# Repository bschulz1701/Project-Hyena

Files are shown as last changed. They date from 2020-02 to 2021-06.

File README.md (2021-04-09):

# Project-Hyena
Daughterboard for use with Feather form factor controller, designed to interface with multiple, flexible, low cost sensors at the core of a low cost meteorological sensing system. 

# Repo Outline
#### [Documents](Documents/) 

General document and image storage for repo and README

#### [Hardware](Hardware/)

Current board files (Eagle), Bill of Materials (BoM), and other design documents

#### [Production](Production/)

Contains the various Gerber and pick and place files required to have the Printed Circuit Boards (PCBs) manufactured or populated 

#### [Software](Software/)

The software associated with the piece of hardware, this is usually diagnostic software used for verifying or investigating the hardware

#### [Testing](Testing/)

Scripts and results from the testing process and development process. Contains more detailed information about documented issues among other testing. 

## Overview
* **Type:** Data Logger/Daughterboard 
* **Interfaces:** I<sup>2</sup>C, GPIO, Pulse
* **Release Version:** v0.2 - 2020/07/15

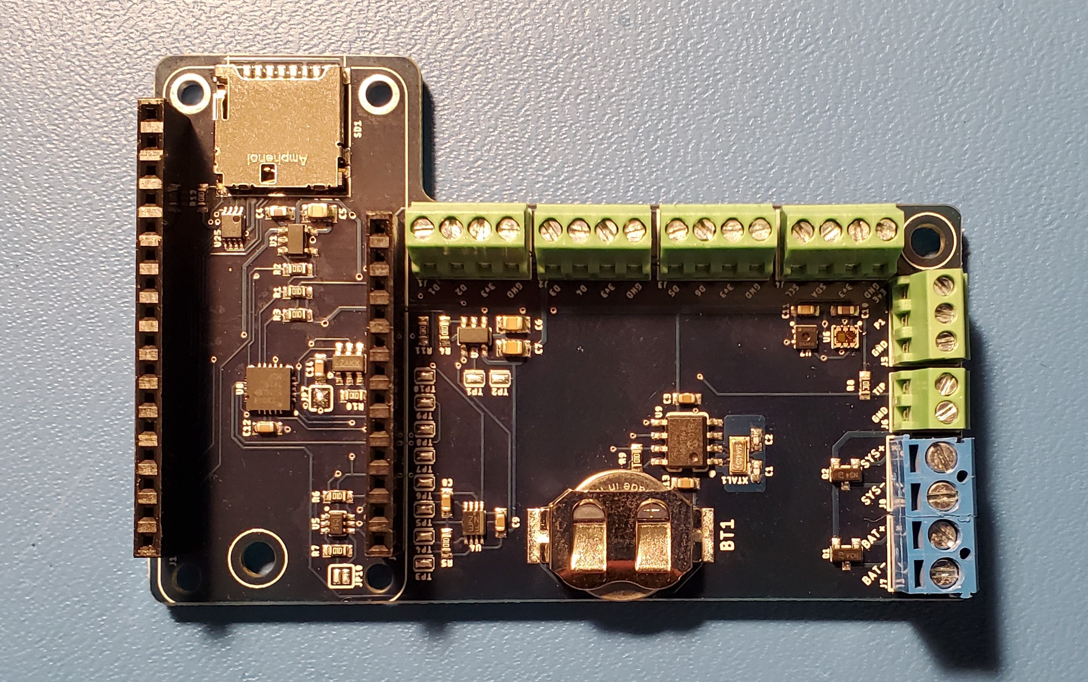
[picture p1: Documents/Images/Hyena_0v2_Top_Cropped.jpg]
Hyena v0.2 - Top


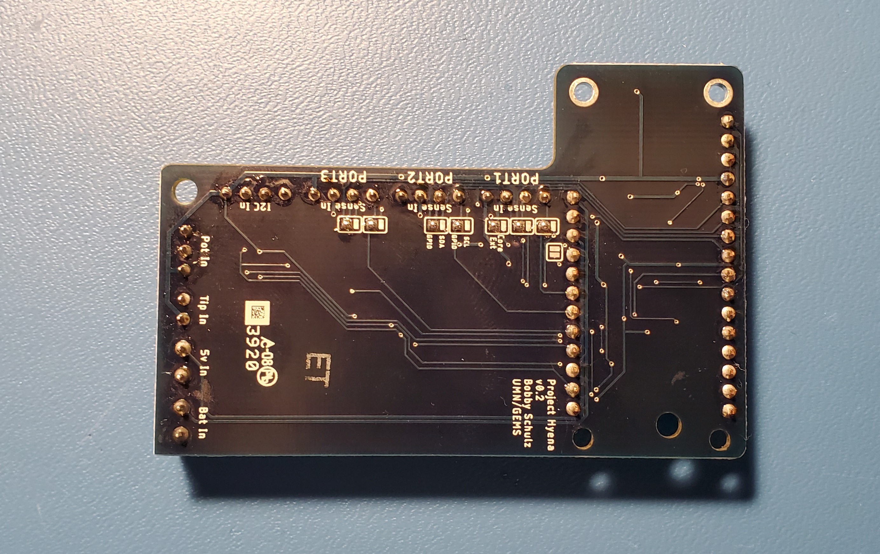
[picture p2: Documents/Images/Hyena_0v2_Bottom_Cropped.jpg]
Hyena v0.2 - Bottom


## Features
### On-Board
* Micro SD Card 
* RTC w/Battery Backup
* Temperature/Pressure/RH Sensor
* RGB Ambient Light Sensor
* Reverse Polarity Power Protected Inputs 

### Interface
* Tipping Bucket Input (SPST switch compatible)
* Dedicated Potentiometric Input (x1) 
* Flexible Sensor Inputs (x3)
* Dedicated I<sup>2</sup>C Input (x1) 
* Supports Particle and other Feather based controllers 

## Specifications
* **Sensor Voltage:** 3.3V
* **Sensor Current (Max):** 500mA (Combined)

## Jumper Settings 

**Port Select Jumpers**
| Jumper | Purpose | Position 1 | Position 2 | 
| --- | --- | --- | --- |
| `JP1`	| GPIO vs I<sup>2</sup>C - Port 1 Digital | Select I2C | Select GPIO | 
| `JP2` | GPIO vs I<sup>2</sup>C - Port 1 Analog | Select I2C | Select GPIO | 
| `JP3` | GPIO vs I<sup>2</sup>C - Port 2 Digital | Select I2C | Select GPIO | 
| `JP4` | GPIO vs I<sup>2</sup>C - Port 2 Analog | Select I2C | Select GPIO | 
| `JP5` | GPIO vs I<sup>2</sup>C - Port 3 Digital | Select I2C | Select GPIO | 
| `JP6` | GPIO vs I<sup>2</sup>C - Port 3 Analog | Select I2C | Select GPIO | 
| `JP8` | Power Select (Core vs Ext) - Port 1 | Core Power for Port 1 | External Switched Power for Port 1 |

**Configuration Jumpers**
| Jumper | Purpose | Open | Closed | Default | 
| --- | --- | --- | --- | ----- |
| `JP7` | Enable Hardware WDT | WDT Disabled | WDT Enabled | Closed |  
| `JP9` | Pullup for Port 1 Digital GPIO | Pullup Disabled | Pullup Enabled | Open |
| `JP10` | Gang On-Board and External I2C Buses | I2C Combined | I2C Isolated | Open | 

## Known Issues/Errata

#### WDT Disable

**Issue:** If using Particle Boron as controller and if you have the WDT disabled (leave `JP7` open), the system fails to run properly, or has sporadic resets. This is likely due to parasitic current on the reset line of the Boron.

**Workaround:** Make sure WDT is enabled by closing `JP7`

#### Solder Jumper Stencil

**Issue:** Depending on the thickness of the solder stencil used for populating the board, the solder jumpers may not bridge when desired. This is due to lack of stencil thickness specification and pad geometry.

**Workaround:** Make a note on the board assembly (if working with a board house) as to which jumpers should be connected (see jumper tables). Otherwise, if assembling manually, check the jumpers are connected, and bridge them using solder wire and a soldering iron if they have failed to jump where desired.

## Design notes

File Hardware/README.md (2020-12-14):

# Hardware Overview - Project Hyena

## Files

* [Legacy](Legacy/) - File storage for older hardware versions  
* PrimaryLogger.sch - Eagle Schematic
* PrimaryLogger.brd - Eagle Board File
* [PrimaryLogger_BoM.csv](PrimaryLogger_BoM.csv) - BoM (For reference only, see [Production](../Production) for production ready BoM)
* [PrimaryLogger.pdf](PrimaryLogger_0v2.pdf) - PDF of Schematic 

## I2C Addresses 

| Device | Address | 
| --- | --- |
| MCP23008 | 0x20 | 
| TCS3400 | 0x39 |
| MCP7940 | 0x6F |
| SHTC3 | 0x70 |

## Pinout

| Particle Pin | Hyena Pin Name | Control | Function | 
| --- | --- | --- | --- |
| 8 | `3V3_EXT_EN` | Output | Enables the external 3.3v rail (active high, nominally low) | 
| 7 | `WD_HOLD` | Output | Controls the hardware watchdog timer, pulse high to "feed" timer |
| 6 | `GPIO1D` | IO | General digital IO pin for external sensors (J1 Connector) | 
| 5 | `GPIO2D` | IO | General digital IO pin for external sensors (J2 Connector) | 
| 4 | `GPIO3D` | IO | General digital IO pin for external sensors (J3 Connector) | 
| 3 | `RTC_INT` | Input | Interrupt line from RTC, natively high active low (open drain), triggers on falling edge |
| 2 | `SDA_CTRL` | Output | Used to turn internal I2C on or off (active high, I2C_OB on, natively low) |
| 1 | `SCL` | Output | I2C clock line |
| 0 | `SDA` | IO | I2C Data line |
| 9 | `3V3_SD_EN` | Output | Enable line for SD card 3.3v supply (active high, natively low) |
| 10 | `IO_EXP_INT` | Input | Global interrupt from the IO expander (functionality configurable via software) |
| 11 | `MISO` | Input | MasterInSlaveOut, part of SPI bus |
| 12 | `MOSI` | Output | MasterOutSlaveIn, part of SPI bus | 
| 13 | `SCK` | Output | SerialClocK, part of SPI bus | 
| 14 | `SD_CS` | Output | SD chip select line, active low |
| 15/ADC4 | `TIP` | IO | Designed as tipping bucket rain gauge input, connected to J6, pulled high by default |
| 16/ADC3 | `GPIOXA` | IO | Intended as analog input for potentiometric input (J5) |
| 17/ADC2 | `GPIO1A` | IO | General digital/analog IO pin for external sensors (J1 Connector) |
| 18/ADC1 | `GPIO2A` | IO | General digital/analog IO pin for external sensors (J2 Connector) |
| 19/ADC0 | `GPIO3A` | IO | General digital/analog IO pin for external sensors (J3 Connector) |

| IO Expander Pin | Hyena Pin Name | Control | Function |
| --- | --- | --- | --- |
| 0 | `3V3_EXT_FAULT` | Input | Monitor pin for external 3v3 rail, if over current trip, pin is pulled low, natively high |
| 1 | `3V3_SD_FAULT` | Input | Monitor pin for SD card 3v3 rail, if over current trip, pin is pulled low, natively high |
| 2 | `SD_CD` | Input | Card detect pin for SD card, natively high, pulled low to indicate physical presence of SD card | 
| 3 | `I2C_EXT_EN` | Output | Control line for external I2C buffer, natively high (on), can be pulled low to turn off the external I2C bus | 
| 4 | `PAR_INT` | Input | Event interrupt line from TCS3400 light sensor (used for PAR measurement), active low interrupt |

## Hardware Testing:
See Testing sub folder

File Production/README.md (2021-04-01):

# Production
This folder contains files used to have the hardware manufactured 

## Files

#### Version v0.2 - Release Version

* [Geber](0v2_Release/PrimaryLogger_2020-09-17_x274.zip)
* [Top Mount](0v2_Release/PrimaryLogger_v2.mnt)
* [BoM](0v2_Release/PrimaryLogger_v2_BoM.csv)

### File Conventions 
* `HardwareName.mnb` - These are mount files (pick and place) for the bottom of the board
* `HardwareName.mnt` - These are mount files (pick and place) for the top of the board
* `HardwareName_YYYY-MM-DD_x274.zip` - These are Gerber (PCB) files from a given date in x274 format, which is accepted by most board houses   

#### Notes:

* Take note of Solder Jumper Stencil issue under Errata 
* A [CR1220](https://www.digikey.com/en/products/detail/panasonic-bsg/CR1220/269740) coin cell battery is required

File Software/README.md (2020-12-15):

# Software
Used for testing or as an accompaniment to hardware devices 

## Files
### Dev

* [`ExternalResetTest.ino`](ExternalResetTest/ExternalResetTest.ino)
	* Development program used to measure timing/functionality of hardware WDT

### Diagnostics 

*  [`HardwareTest.ino`](HardwareTest/HardwareTest.ino)
	* A test designed to be run on a feather board installed in the logger to test the functionality of the system, used to verify the daughterboard hardware

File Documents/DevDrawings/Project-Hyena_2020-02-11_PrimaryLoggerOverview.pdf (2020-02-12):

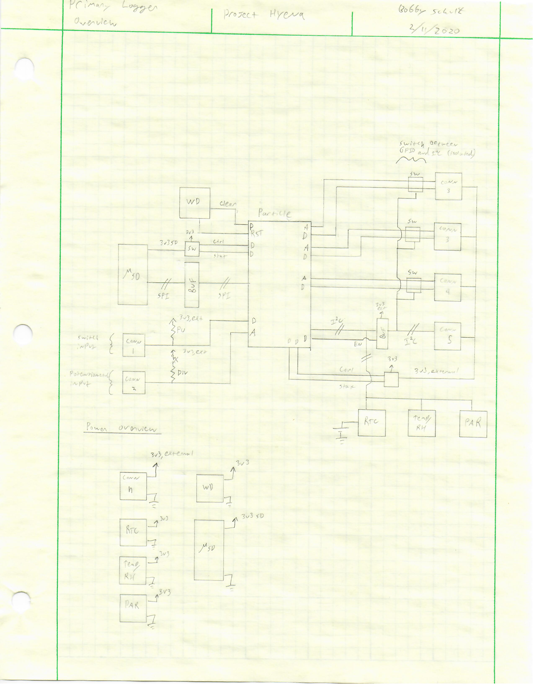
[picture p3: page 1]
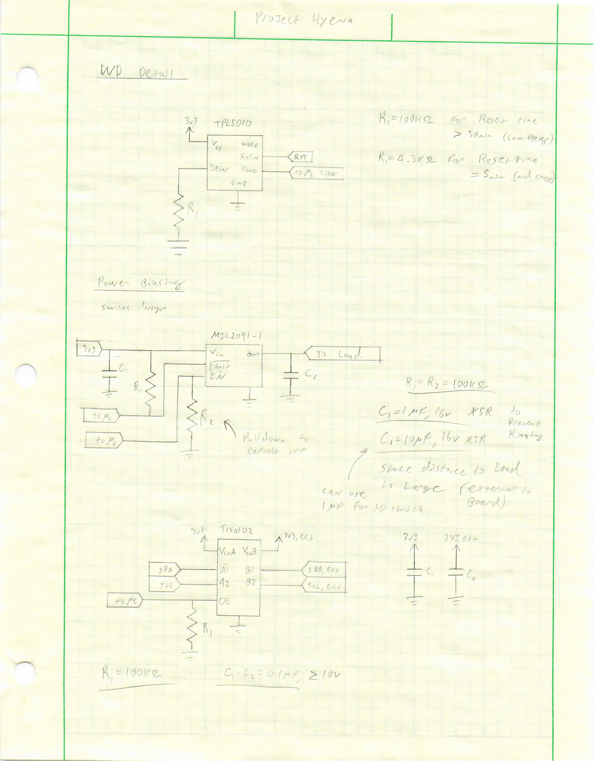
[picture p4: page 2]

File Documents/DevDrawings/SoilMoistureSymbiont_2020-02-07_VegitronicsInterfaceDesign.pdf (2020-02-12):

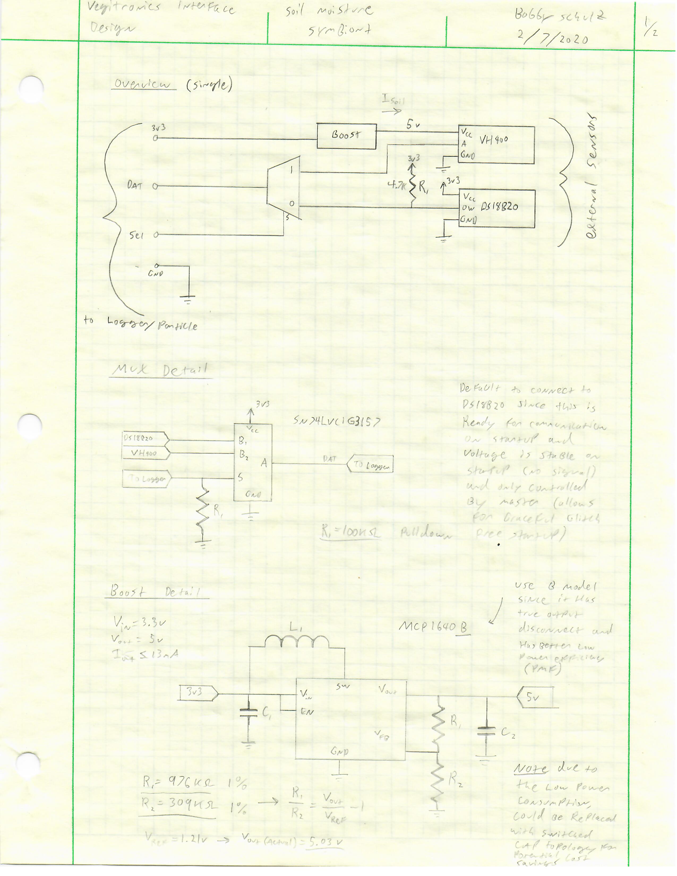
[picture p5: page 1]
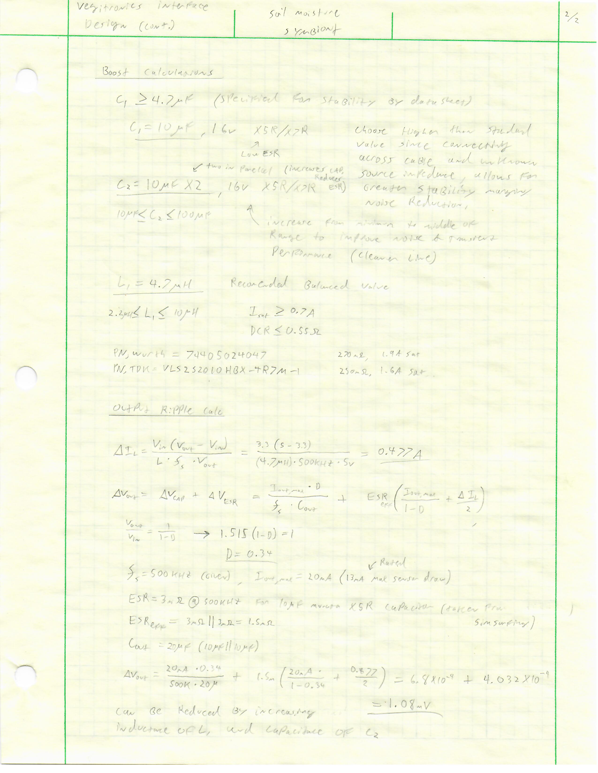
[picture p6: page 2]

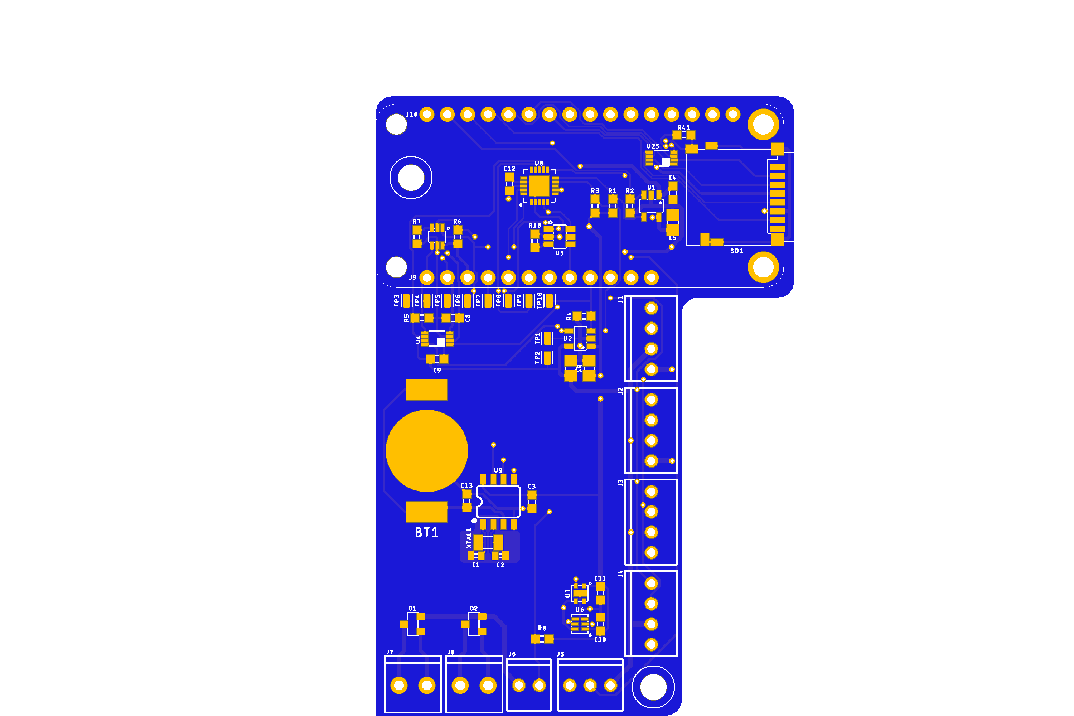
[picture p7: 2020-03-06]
Hardware/PrimaryLogger_0v0_Render.png

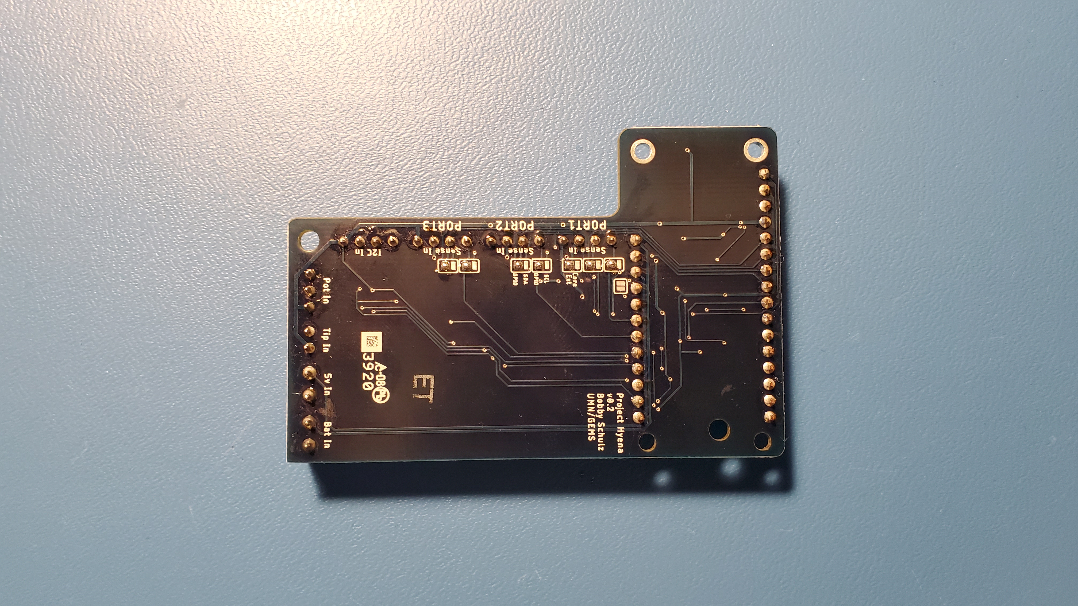
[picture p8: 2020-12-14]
Documents/Images/Hyena_0v2_Bottom.jpg

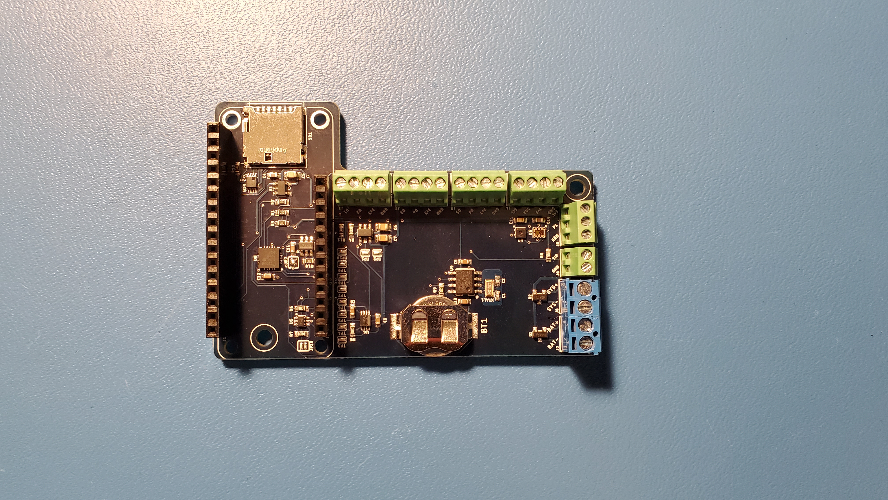
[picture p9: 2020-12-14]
Documents/Images/Hyena_0v2_Top.jpg

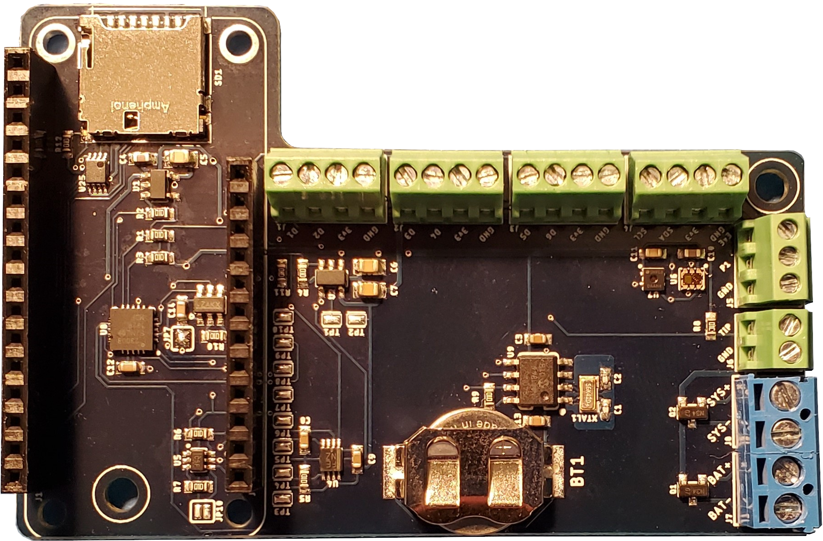
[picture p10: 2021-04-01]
Documents/Images/Hyena_0v2_Top_Cropped.png

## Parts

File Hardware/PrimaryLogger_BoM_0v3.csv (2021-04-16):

Qty | Value | Device | Package | Parts | Description | DIGIKEY | DISP | MF | MPN | VALUE | VALUE_PART
1 |  | CONN_022.54_SCREW_ROUND | 1X02_2.54_SCREWTERM_ROUND | J8 | Genaric 2 terminal header | ED10561-ND |  | OnShore | OSTVN02A150
2 |  | CONN_023.5MM_ROUND | SCREWTERMINAL-3.5MM-2_ROUND | J6, J7 | Genaric 2 terminal header | ED2635-ND |  | OnShore | OSTTE020161
2 |  | MOUNTING_HOLE2_NP | 2_56 | H1, H2 | Genaric Mechanical Mounting Hole | DNP |  | N/A | DNP
9 | 0.1uF | C-EU0.1UFC0603 | C0603 | C1, C2, C3, C7, C8, C9, C10, C16, C17 | CAPACITOR, European symbol | 490-6051-1-ND |  | Murata | GCM188R71E104KA57D
2 | 0R | R-EU_0.0R0603 | R0603 | R2, R16 | RESISTOR, European symbol | 311-0.0LECT-ND |  | Yageo | AC0603JR-070RL |  | 0
11 | 100k | R-EU_100KR0603 | R0603 | R1, R3, R4, R5, R7, R8, R13, R15, R18, R21, R22 | RESISTOR, European symbol | 311-100KHRCT-ND |  | Yageo | RC0603FR-07100KL |  | 100k
4 | 10k | R-EU_10KR0603 | R0603 | R6, R9, R10, R14 | RESISTOR, European symbol | 311-10.0KHRCT-ND |  | Yageo | RC0603FR-0710KL |  | 10k
4 | 10uF | C-EU10UFC0805 | C0805 | C11, C13, C14, C15 | CAPACITOR, European symbol | 490-6473-6-ND |  | Murata | GRM21BR61C106KE15K
1 | 1k | R-EU_1KR0603 | R0603 | R17 | RESISTOR, European symbol | 311-1KLDCT-ND |  | Yageo | AC0603FR-071KL |  | 1k
2 | 1uF | C-EU1UFC0603 | C0603 | C4, C12 | CAPACITOR, European symbol | 587-1251-1-ND |  | Yaiyo Yuden | EMK107BJ105KA-T
6 | 4.7k | R-EU_4.7KR0603 | R0603 | R11, R12, R19, R20, R23, R24 | RESISTOR, European symbol | 311-4.70KHRCT-ND |  | Yageo | RC0603FR-074K7L |  | 4.7k
2 | 6pF | C-EU6PFC0402 | C0402 | C5, C6 | CAPACITOR, European symbol | 490-3104-1-ND |  | Murata | GJM1555C1H6R0CB01D
1 | BATTERY_COIN12MM | BATTERY_COIN12MM | LINX_BAT-HLD-012-SMT | BT1 | Coin Cell Battery Holder | BAT-HLD-012-SMT-ND |  | Linx | BAT-HLD-012-SMT
1 | CONN_32.54_SCREW | CONN_32.54_SCREW | 1X03_SCREW | J5 | Genaric 3 terminal header | ED10562-ND |  | On Shore | OSTVN03A150
4 | CONN_42.54_SCREW | CONN_42.54_SCREW | 1X04_SCREW | J1, J2, J3, J4 | Genaric 4 terminal header | ED10563-ND |  | On Shore | OSTVN04A150
1 | CRYSTAL3.2X1.5 | CRYSTAL3.2X1.5 | CRYSTAL_3.2X1.5_2-SMD | XTAL1 | Crystal Oscilator | 535-11937-1-ND |  | ABS07-120-32.768KHZ-T | Abracon
2 | DMG3404 | MOSFET-NCH-DMG3404L | SOT23-3 | Q1, Q2 | N-channel MOSFETs | DMG3404L-7DICT-ND |  | Diodes Incorporated | DMG3404L-7 | DMG3404
1 | FEATHERWING_NODIM | FEATHERWING_NODIM | FEATHERWING_DIM | MS1
1 | GEMS_POWER_PLUGINPUT | GEMS_POWER_PLUGINPUT | 2X3_MICROFIT_RT | J9 | Power Plug For GEMS Based SystemsBoth Input and Output versions | WM1815-ND | Input | Molex | 0430450600
1 | JUMPER-SMT_2_NC_PASTE_SILK | JUMPER-SMT_2_NC_PASTE_SILK | SMT-JUMPER_2_NC_PASTE_SILK | JP8 | Normally closed solder jumper | DNP |  | N/A | N/A
7 | JUMPER-SMT_3_1-NC_PASTE_SILK | JUMPER-SMT_3_1-NC_PASTE_SILK | SMT-JUMPER_3_1-NC_PASTE_SILK | JP1, JP2, JP3, JP4, JP5, JP6, JP7 | Normally closed solder jumper (1 of 2 connections) | DNP |  | N/A | N/A
1 | LEDGREEN0603 | LEDGREEN0603 | LED_0603 | D2 | Genaric LED | 732-4971-1-ND |  | Wurth | 150060GS75000
2 | LEDRED0603 | LEDRED0603 | LED_0603 | D1, D3 | Genaric LED | 732-4978-1-ND |  | Wurth | 150060RS75000
1 | MCP23008SSOP | MCP23008SSOP | SSOP20 | U3 | MCP23008 - I2C I/O Expander, 8 bit wtih interrupt and reset | MCP23008T-E/SSCT-ND |  | Microchip | MCP23008T-E/SS
1 | MCP79412SOIC | MCP79412SOIC | SO08 | U1 | MCP794xx - Battery Backed I2C Real Time Clock (RTC) with SRAM (EEPROM*) and Protected EERPOM | MCP79412-I/SN-ND | MCP79412 | Microchip | MCP79412-I/SN
2 | MIC2005 | MIC2005 | SOT23-5 | U7, U8 | MIC2005 - Hight Side Load Switch, with Fixed Current Limit | 576-3462-1-ND | MIC2005 | Microchip | MIC2005A-1YM5-TR
1 | MIC842L | MIC842L | DCK_R-PDSO-G5 | U9 | Comparator with internal voltage referance (1.24V), 5V and 3.3V compatable, 20mA output current | 576-2927-1-ND |  | Microchip | MIC842LYC5-TR
1 | MICRO_SD | MICRO_SD | CUSTOM-PARTS_SD_MICRO | SD1 | Micro SD Card - Card Detect, Exposed leads for non-reflow soldering | 114-00841-68-1-ND |  | Amphenol | 114-00841-68
1 | PCA9617TSSOP8 | PCA9617TSSOP8 | TTSOP_8 | U10 | PCA9617A - Level translating I2C Bus Repeater | 568-10211-2-ND |  | NXP | PCA9617ADPJ
1 | SHTC3DFN | SHTC3DFN | DFN_4_2X2 | U4 | SHTCx - Digital Humidity and Temperature Sensor | 1649-1100-1-ND | SHTC3 | Sensirion | SHTC3
1 | SN74AUP3G34DCU | SN74AUP3G34DCU | DCU_(R-PDSO-G8) | U11 | SN74AUP3G34 - Logic Buffer | 296-25595-1-ND |  | TI | SN74AUP3G34DCUR
1 | SN74LVC1G3157SC70 | SN74LVC1G3157SC70 | DCK_R-PDSO-G6 | U12 | SN74LVC1G3157 - SPDT Analog Switch | 296-14909-1-ND | SN74LVC1G3157 | TI | SN74LVC1G3157DCKR
1 | TCS3400 | TCS3400 | TCS3400 | U5 | TCS3400 - Ambient Multi-Band Light Sensor with I2C Interface | TCS34003FNMCT-ND |  | AMS | TCS34003FNM
10 | TESTPOINTRCU | TESTPOINTRCU | TESTPOINT_0603 | TP1, TP2, TP3, TP4, TP5, TP6, TP7, TP8, TP9, TP10 |  | A106145CT-ND |  | TE Connectivity | RCU-0C
2 | TPL5010DDC | TPL5010DDC | DDC_R-PDSO-G6 | U2, U6 | TPL5010 - Nano-Power System Timer with Watchdog Functionality | 296-38829-1-ND |  | TI | TPL5010DDCT

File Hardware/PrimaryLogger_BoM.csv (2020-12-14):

Qty | Value | Device | Package | Parts | Description | DIGIKEY | DISP | MF | MPN | VALUE | VALUE_PART
1 |  | CONN_022.54_SCREW_ROUND | 1X02_2.54_SCREWTERM_ROUND | J6 | Genaric 2 terminal header | ED10561-ND |  | OnShore | OSTVN02A150
2 |  | CONN_023.5MM_ROUND | SCREWTERMINAL-3.5MM-2_ROUND | J7, J8 | Genaric 2 terminal header | ED2635-ND |  | OnShore | OSTTE020161
2 |  | MOUNTING_HOLE4_NP | 4_40 | H1, H2 | Genaric Mechanical Mounting Hole | DNP |  | N/A | DNP
7 | 0.1uF | C-EU0.1UFC0603 | C0603 | C3, C8, C9, C11, C12, C13, C14 | CAPACITOR, European symbol | 490-6051-1-ND |  | Murata | GCM188R71E104KA57D
11 | 100k | R-EU_100KR0603 | R0603 | R1, R2, R3, R4, R5, R6, R7, R9, R10, R11, R12 | RESISTOR, European symbol | 311-100KHRCT-ND |  | Yageo | RC0603FR-07100KL |  | 100k
1 | 100k | R-EU_10KR0603 | R0603 | R8 | RESISTOR, European symbol | 311-10.0KHRCT-ND |  | Yageo | RC0603FR-0710KL |  | 10k
3 | 10uF | C-EU10UFC0805 | C0805 | C5, C6, C7 | CAPACITOR, European symbol | 490-6473-6-ND |  | Murata | GRM21BR61C106KE15K
2 | 1uF | C-EU1UFC0603 | C0603 | C4, C10 | CAPACITOR, European symbol | 587-1251-1-ND |  | Yaiyo Yuden | EMK107BJ105KA-T
2 | 6pF | C-EU6PFC0402 | C0402 | C1, C2 | CAPACITOR, European symbol | 490-3104-1-ND |  | Murata | GJM1555C1H6R0CB01D
1 | BATTERY_COIN12MM | BATTERY_COIN12MM | LINX_BAT-HLD-012-SMT | BT1 | Coin Cell Battery Holder | BAT-HLD-012-SMT-ND |  | Linx | BAT-HLD-012-SMT
1 | CONN_32.54_SCREW | CONN_32.54_SCREW | 1X03_SCREW | J5 | Genaric 3 terminal header | ED10562-ND |  | On Shore | OSTVN03A150
4 | CONN_42.54_SCREW | CONN_42.54_SCREW | 1X04_SCREW | J1, J2, J3, J4 | Genaric 4 terminal header | ED10563-ND |  | On Shore | OSTVN04A150
1 | CRYSTAL3.2X1.5 | CRYSTAL3.2X1.5 | CRYSTAL_3.2X1.5_2-SMD | XTAL1 | Crystal Oscilator | 535-11937-1-ND |  | ABS07-120-32.768KHZ-T | Abracon
2 | DMG3404 | MOSFET-NCH-DMG3404L | SOT23-3 | Q1, Q2 | N-channel MOSFETs | DMG3404L-7DICT-ND |  | Diodes Incorporated | DMG3404L-7 | DMG3404
1 | FEATHERWING_NODIM | FEATHERWING_NODIM | FEATHERWING_DIM | MS1
2 | JUMPER-SMT_2_NC_PASTE_SILK | JUMPER-SMT_2_NC_PASTE_SILK | SMT-JUMPER_2_NC_PASTE_SILK | JP7, JP9 | Normally closed solder jumper | DNP |  | N/A | N/A
1 | JUMPER-SMT_2_NO_SILK | JUMPER-SMT_2_NO_SILK | SMT-JUMPER_2_NO_SILK | JP10 | Normally open jumper | DNP |  | N/A | N/A
7 | JUMPER-SMT_3_1-NC_PASTE_SILK | JUMPER-SMT_3_1-NC_PASTE_SILK | SMT-JUMPER_3_1-NC_PASTE_SILK | JP1, JP2, JP3, JP4, JP5, JP6, JP8 | Normally closed solder jumper (1 of 2 connections) | DNP |  | N/A | N/A
1 | MCP23008QFN | MCP23008QFN | QFN20 | U8 | MCP23008 - I2C I/O Expander, 8 bit wtih interrupt and reset | MCP23008T-E/MLCT-ND |  | Microchip | MCP23008T-E/ML
1 | MCP7940SOIC | MCP7940SOIC | SO08 | U9 | MCP7940 - RTC | MCP7940N-I/SN-ND |  | Microchip | MCP7940N-I/SN
2 | MIC2005 | MIC2005 | SOT23-5 | U1, U2 | MIC2005 - Hight Side Load Switch, with Fixed Current Limit | 576-3462-1-ND | MIC2005 | Microchip | MIC2005A-1YM5-TR
1 | MICRO_SD | MICRO_SD | CUSTOM-PARTS_SD_MICRO | SD1 | Micro SD Card - Card Detect, Exposed leads for non-reflow soldering | 114-00841-68-1-ND |  | Amphenol | 114-00841-68
1 | SHTC3DFN | SHTC3DFN | DFN_4_2X2 | U7 | SHTCx - Digital Humidity and Temperature Sensor | 1649-1100-1-ND | SHTC3 | Sensirion | SHTC3
1 | SN74AUP3G34DCU | SN74AUP3G34DCU | DCU_(R-PDSO-G8) | U25 | SN74AUP3G34 - Logic Buffer | 296-25595-1-ND |  | TI | SN74AUP3G34DCUR
1 | SN74LVC1G3157SC70 | SN74LVC1G3157SC70 | DCK_R-PDSO-G6 | U5 | SN74LVC1G3157 - SPDT Analog Switch | 296-14909-1-ND | SN74LVC1G3157 | TI | SN74LVC1G3157DCKR
1 | TCS3400 | TCS3400 | TCS3400 | U6 | TCS3400 - Ambient Multi-Band Light Sensor with I2C Interface | TCS34003FNMCT-ND |  | AMS | TCS34003FNM
10 | TESTPOINTRCU | TESTPOINTRCU | TESTPOINT_0603 | TP1, TP2, TP3, TP4, TP5, TP6, TP7, TP8, TP9, TP10 |  | A106145CT-ND |  | TE Connectivity | RCU-0C
1 | TPL5010DDC | TPL5010DDC | DDC_R-PDSO-G6 | U3 | TPL5010 - Nano-Power System Timer with Watchdog Functionality | 296-38829-1-ND |  | TI | TPL5010DDCT
1 | TXS0102DCU | TXS0102DCU | DCU_(R-PDSO-G8) | U4 | TXS0102 - 2 Channel Bidirectional Voltage Level Translator | 296-21931-1-ND |  | TI | TXS0102DCUR

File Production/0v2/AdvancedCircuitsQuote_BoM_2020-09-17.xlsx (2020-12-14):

Description | Qty | Ref Des | Mfg P/N | Manufacturer | Distributor P/N
Genaric 2 terminal header | 1 | J6 | OSTVN02A150 | OSTVN02A150 | ED10561-ND
Genaric 2 terminal header | 2 | J7, J8 | OSTTE020161 | OSTTE020161 | ED2635-ND
Genaric Mechanical Mounting Hole | 2 | H1, H2 | DNP | DNP | DNP
CAPACITOR, European symbol | 7 | C3, C8, C9, C11, C12, C13, C14 | GCM188R71E104KA57D | GCM188R71E104KA57D | 490-6051-1-ND
RESISTOR, European symbol | 11 | R1, R2, R3, R4, R5, R6, R7, R9, R10, R11, R12 | RC0603FR-07100KL | RC0603FR-07100KL | 311-100KHRCT-ND
RESISTOR, European symbol | 1 | R8 | RC0603FR-0710KL | RC0603FR-0710KL | 311-10.0KHRCT-ND
CAPACITOR, European symbol | 3 | C5, C6, C7 | GRM21BR61C106KE15K | GRM21BR61C106KE15K | 490-6473-6-ND
CAPACITOR, European symbol | 2 | C4, C10 | EMK107BJ105KA-T | EMK107BJ105KA-T | 587-1251-1-ND
CAPACITOR, European symbol | 2 | C1, C2 | GJM1555C1H6R0CB01D | GJM1555C1H6R0CB01D | 490-3104-1-ND
Coin Cell Battery Holder | 1 | BT1 | BAT-HLD-012-SMT | BAT-HLD-012-SMT | BAT-HLD-012-SMT-ND
Genaric 3 terminal header | 1 | J5 | OSTVN03A150 | OSTVN03A150 | ED10562-ND
Genaric 4 terminal header | 4 | J1, J2, J3, J4 | OSTVN04A150 | OSTVN04A150 | ED10563-ND
Crystal Oscilator | 1 | XTAL1 | Abracon | Abracon | 535-11937-1-ND
N-channel MOSFETs | 2 | Q1, Q2 | DMG3404L-7 | DMG3404L-7 | DMG3404L-7DICT-ND
Normally closed solder jumper | 2 | JP7, JP9 | N/A | N/A | DNP
Normally open jumper | 1 | JP10 | N/A | N/A | DNP
Normally closed solder jumper (1 of 2 connections) | 7 | JP1, JP2, JP3, JP4, JP5, JP6, JP8 | N/A | N/A | DNP
MCP23008 - I2C I/O Expander, 8 bit wtih interrupt and reset | 1 | U8 | MCP23008T-E/ML | MCP23008T-E/ML | MCP23008T-E/MLCT-ND
MCP7940 - RTC | 1 | U9 | MCP7940N-I/SN | MCP7940N-I/SN | MCP7940N-I/SN-ND
MIC2005 - Hight Side Load Switch, with Fixed Current Limit | 2 | U1, U2 | MIC2005A-1YM5-TR | MIC2005A-1YM5-TR | 576-3462-1-ND
Micro SD Card - Card Detect, Exposed leads for non-reflow soldering | 1 | SD1 | 114-00841-68 | 114-00841-68 | 114-00841-68-1-ND
SHTCx - Digital Humidity and Temperature Sensor | 1 | U7 | SHTC3 | SHTC3 | 1649-1100-1-ND
SN74AUP3G34 - Logic Buffer | 1 | U25 | SN74AUP3G34DCUR | SN74AUP3G34DCUR | 296-25595-1-ND
SN74LVC1G3157 - SPDT Analog Switch | 1 | U5 | SN74LVC1G3157DCKR | SN74LVC1G3157DCKR | 296-14909-1-ND
TCS3400 - Ambient Multi-Band Light Sensor with I2C Interface | 1 | U6 | TCS34003FNM | TCS34003FNM | TCS34003FNMCT-ND
Generic Test Points | 10 | TP1, TP2, TP3, TP4, TP5, TP6, TP7, TP8, TP9, TP10 | N/A | N/A | DNP
TPL5010 - Nano-Power System Timer with Watchdog Functionality | 1 | U3 | TPL5010DDCT | TPL5010DDCT | 296-38829-1-ND
TXS0102 - 2 Channel Bidirectional Voltage Level Translator | 1 | U4 | TXS0102DCUR | TXS0102DCUR | 296-21931-1-ND
Generic 16 terminal header | 1 | J10 | PPPC161LFBN-RC | Sullins | S7049-ND
Generic 12 terminal header | 1 | J9 | PPPC121LFBN-RC | Sullins | S7045-ND

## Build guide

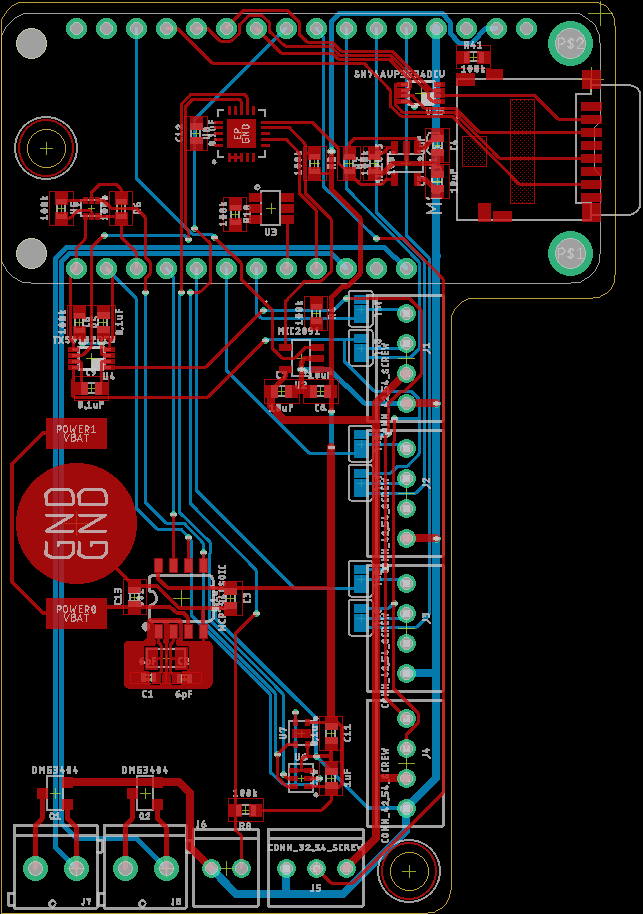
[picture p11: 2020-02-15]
Hardware/BoardPrint_ALPHA.png

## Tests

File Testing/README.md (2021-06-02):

# Testing:
## v0.0
### Hardware Watchdog:
Test functionality of watchdog (TPL5010) timer and confirm function with Particle Boron. 

Tested with Particle Boron connected to Feather socket, board powered via BatIn connection (3.7V power supply). Arduino was connected externally (common ground) and used to measure tripping on reset pin and timing of these pulses. The testing program was [ExternalResetTest](Software/ExternalResetTest/ExternalResetTest.ino). For the first test, the Boron was simply left in an idle state to ensure the watchdog would properly trigger at intervals. For the second test, the watchdog was reset by the Boron (via a high pulse 1ms in durration) every 5 minutes, which should prevent the watchdog from ever triggering. For all tests, a 100k&Omega; set resistor was used for the watchdog timer. 

Calculated period = 2159.65368 s (35.994 min)

T = [(((R<sub>Set</sub> x 2 x A)/100 + B )<sup>2</sup> - B<sup>2</sup>)/(4 x A) + C] / 100

for T > 1000s, A = 0.3177, B = -135.2571, C = 34522.4680 (See [Datasheet](http://www.ti.com/lit/ds/symlink/tpl5010.pdf) for more values/details)

<b>Test 1:</b>

<b>Test 2:</b>

## Alternative Parts:
Alternative clock, v0.4A board

| Previous Manufacturer Part Number | Previous Manufacturer | Alt Manufacturer Part Number | Alt Manufacturer | 
| --- | --- | ---- | ---- |
| ABS07-120-32.768KHZ-T | Abracon | ECS-.327-6-34QN-TR | ECS | 

Alternative crystal oscilation compaired with previous part on the v0.4A board, with MCP79412 RTC

**Standard Part**

Crystal Part Test

Yellow trace is connected to `X1` pin on RTC, blue trace is connected to `X2` pin on RTC, math output is CH1 - CH2

**Alt Part**

Crystal Alternative Part Test

Yellow trace is connected to `X1` pin on RTC, blue trace is connected to `X2` pin on RTC, math output is CH1 - CH2

## Issues:
### <b>Inrush current from Soil Moisture Symbiont (v0.0) trips external power switch</b>
<b>Cause:</b>
When the external switch is triggered with the Soil Moisture Symbiont connected, the inrush current on the soil moisture symbiont exceeds the current limit (100mA) on the load switch (MIC2091) for a long enough time to cause the fault detection to trip and disconnect the output. This results in a locked up state, since on each re-try the same overload occurs. 

Here we see the scope capture of the power on of the soil moisture symbiont when powered by a bench supply (current limit > max draw of soil moisture symbiont)
Power Supply Test

Yellow -> V<sub>Supply</sub>

Blue -> I<sub>Supply</sub> (10V/A)

<b>Potential Solutions:</b>

- Change boost converter on Soil Moisture Symbiont to a synchronous converter to prevent this inrush current. Fixes current problem, but not global potential issue. 
- Change load switch to one with a higher current limit, this would allow the current inrush current spike to be present without tripping the device into a locked out state.

<b>Testing:</b>

Switched the load switch to the MIC2005A load switch (identical pinout), which has a 500mA current limit, but otherwise the same functionality as the previous switch. The test of the system with this switch are seen below

MIC2005A Test

Yellow -> V<sub>Supply</sub>

Blue -> I<sub>Supply</sub> (10V/A)

As you can see, we get the same high value spike, but the switch does not trigger an overload and instead properly switches the output on.

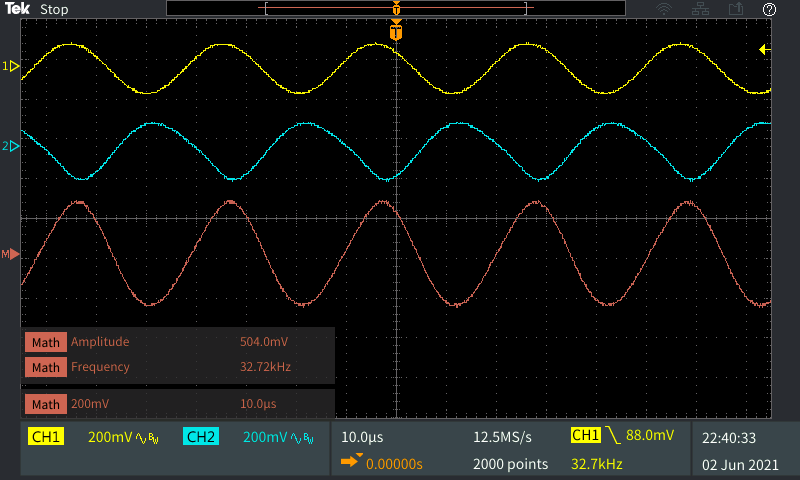
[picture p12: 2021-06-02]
Testing/TestingCaptures/CrystalTest_AltPart.PNG

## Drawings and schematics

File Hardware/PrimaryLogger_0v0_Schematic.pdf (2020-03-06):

A

A

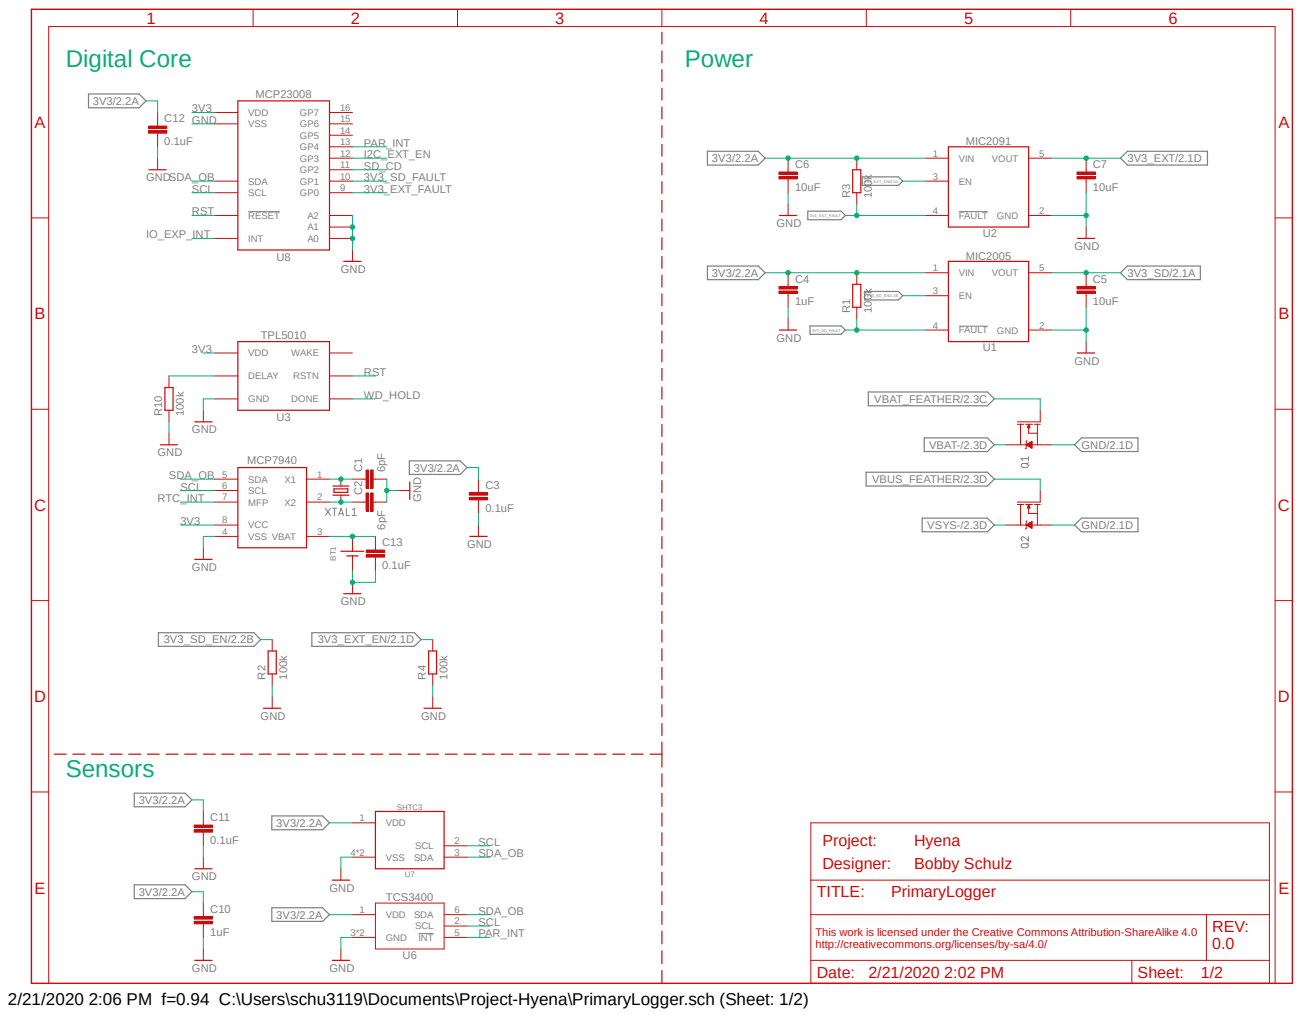
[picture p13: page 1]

This work is licensed under the Creative Commons Attribution-ShareAlike 4.0
http://creativecommons.org/licenses/by-sa/4.0/

TP2 TP1 TP4 TP5 TP6 TP3 TP10 TP7 TP9 TP8 CARD_DETECT CD¹ CARD_DETECT1 CD² | DATA_OUT
1Y | 7 GND 4 | VCC | 8 SN74AUP3G34 U25 A1 5 | A2 4 | VA 3 | VB | 7 EN | 6 B1 | 8 B2 | 1 TXS0102 GND 2 | U4 C8 | C9

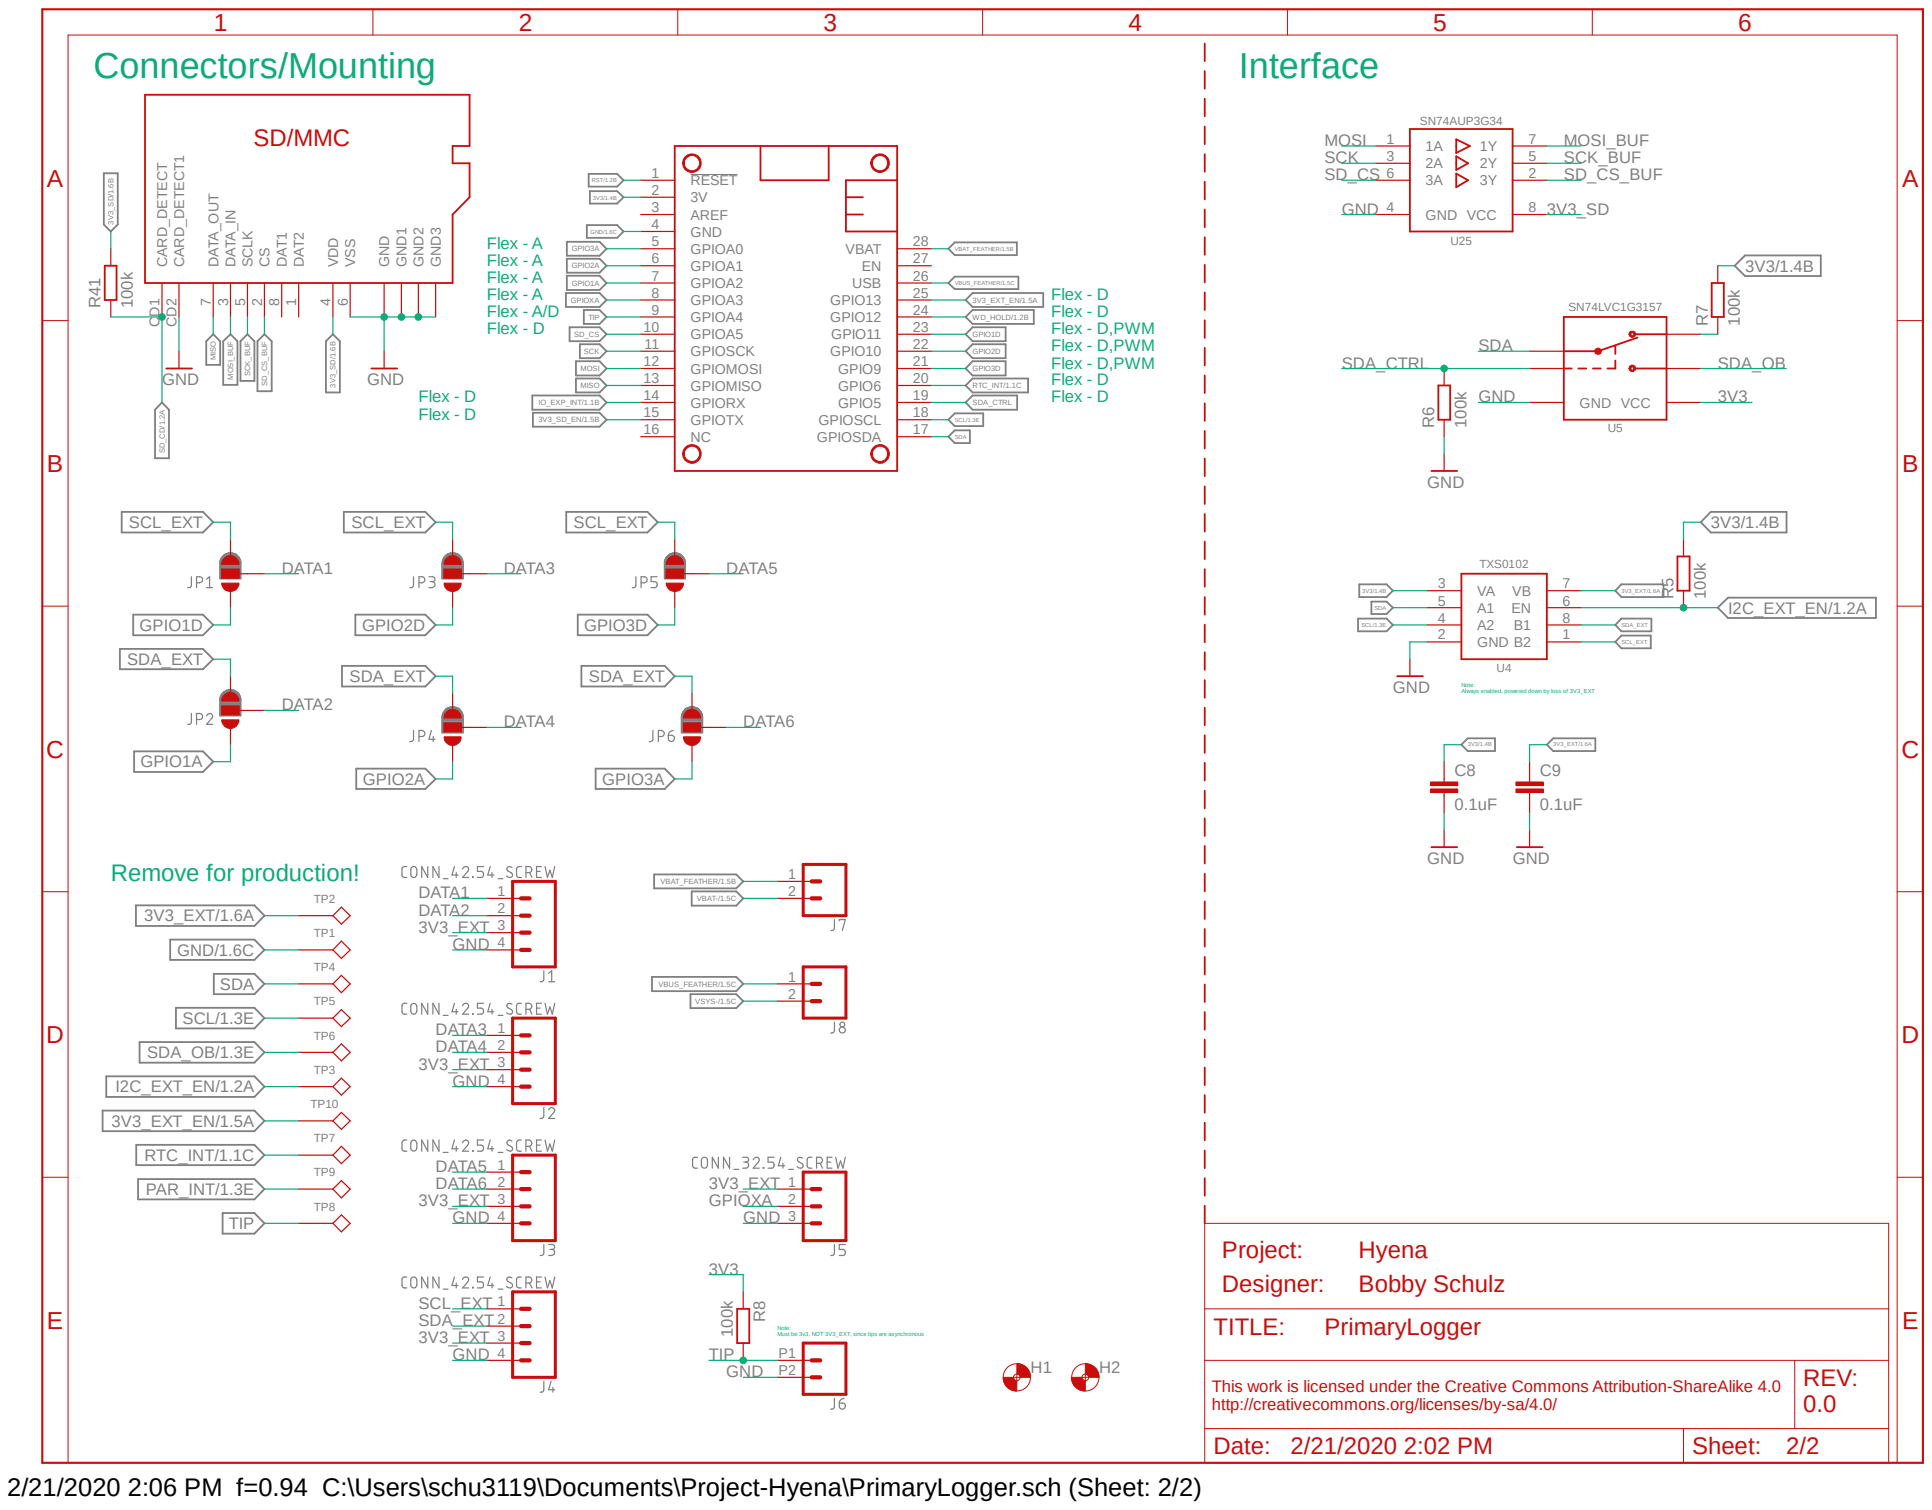
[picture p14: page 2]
GND ¹⁰⁰k; GND; U5 GND; 7 DATA_IN; 3 SCLK; 2 DAT1; 8 DAT2 1 VDD 4 VSS; 6 GND GND1 GND2 GND3 R41; RESET 1; AREF 3; GND 4; GPIOA0 5; GPIOA1 6; GPIOA2 7; GPIOA3 8; GPIOA4 9; GPIOA5 10; GPIOSCK 11; GPIOMOSI 12; GPIOMISO 13; GPIORX 14; GPIOTX 15; GPIOSDA; 17 GPIOSCL; 18 GPIO5; 19 GPIO9; 21 GPIO6; 20 GPIO10; 22 GPIO11; 23 GPIO12; 24 GPIO13; 27 USB; 26 VBAT; GND VCC; SN74LVC1G3157 R⁶; GND/1.6C; SDA; SCL/1.3E; RTC_INT/1.1C; VBAT_FEATHER/1.5B; VBUS_FEATHER/1.5C; 3V3_EXT; 3V3_EXT/1.6A; SDA_EXT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

Note: Always enabled, powered down by loss of 3V3_EXT

Remove for production!

2/21/2020 2:06 PM f=0.94 C:\Users\schu3119\Documents\Project-Hyena\PrimaryLogger.sch (Sheet: 2/2) ¹⁰⁰k

0.0 Note: Must be 3v3, NOT 3V3_EXT, since tips are asynchronous

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

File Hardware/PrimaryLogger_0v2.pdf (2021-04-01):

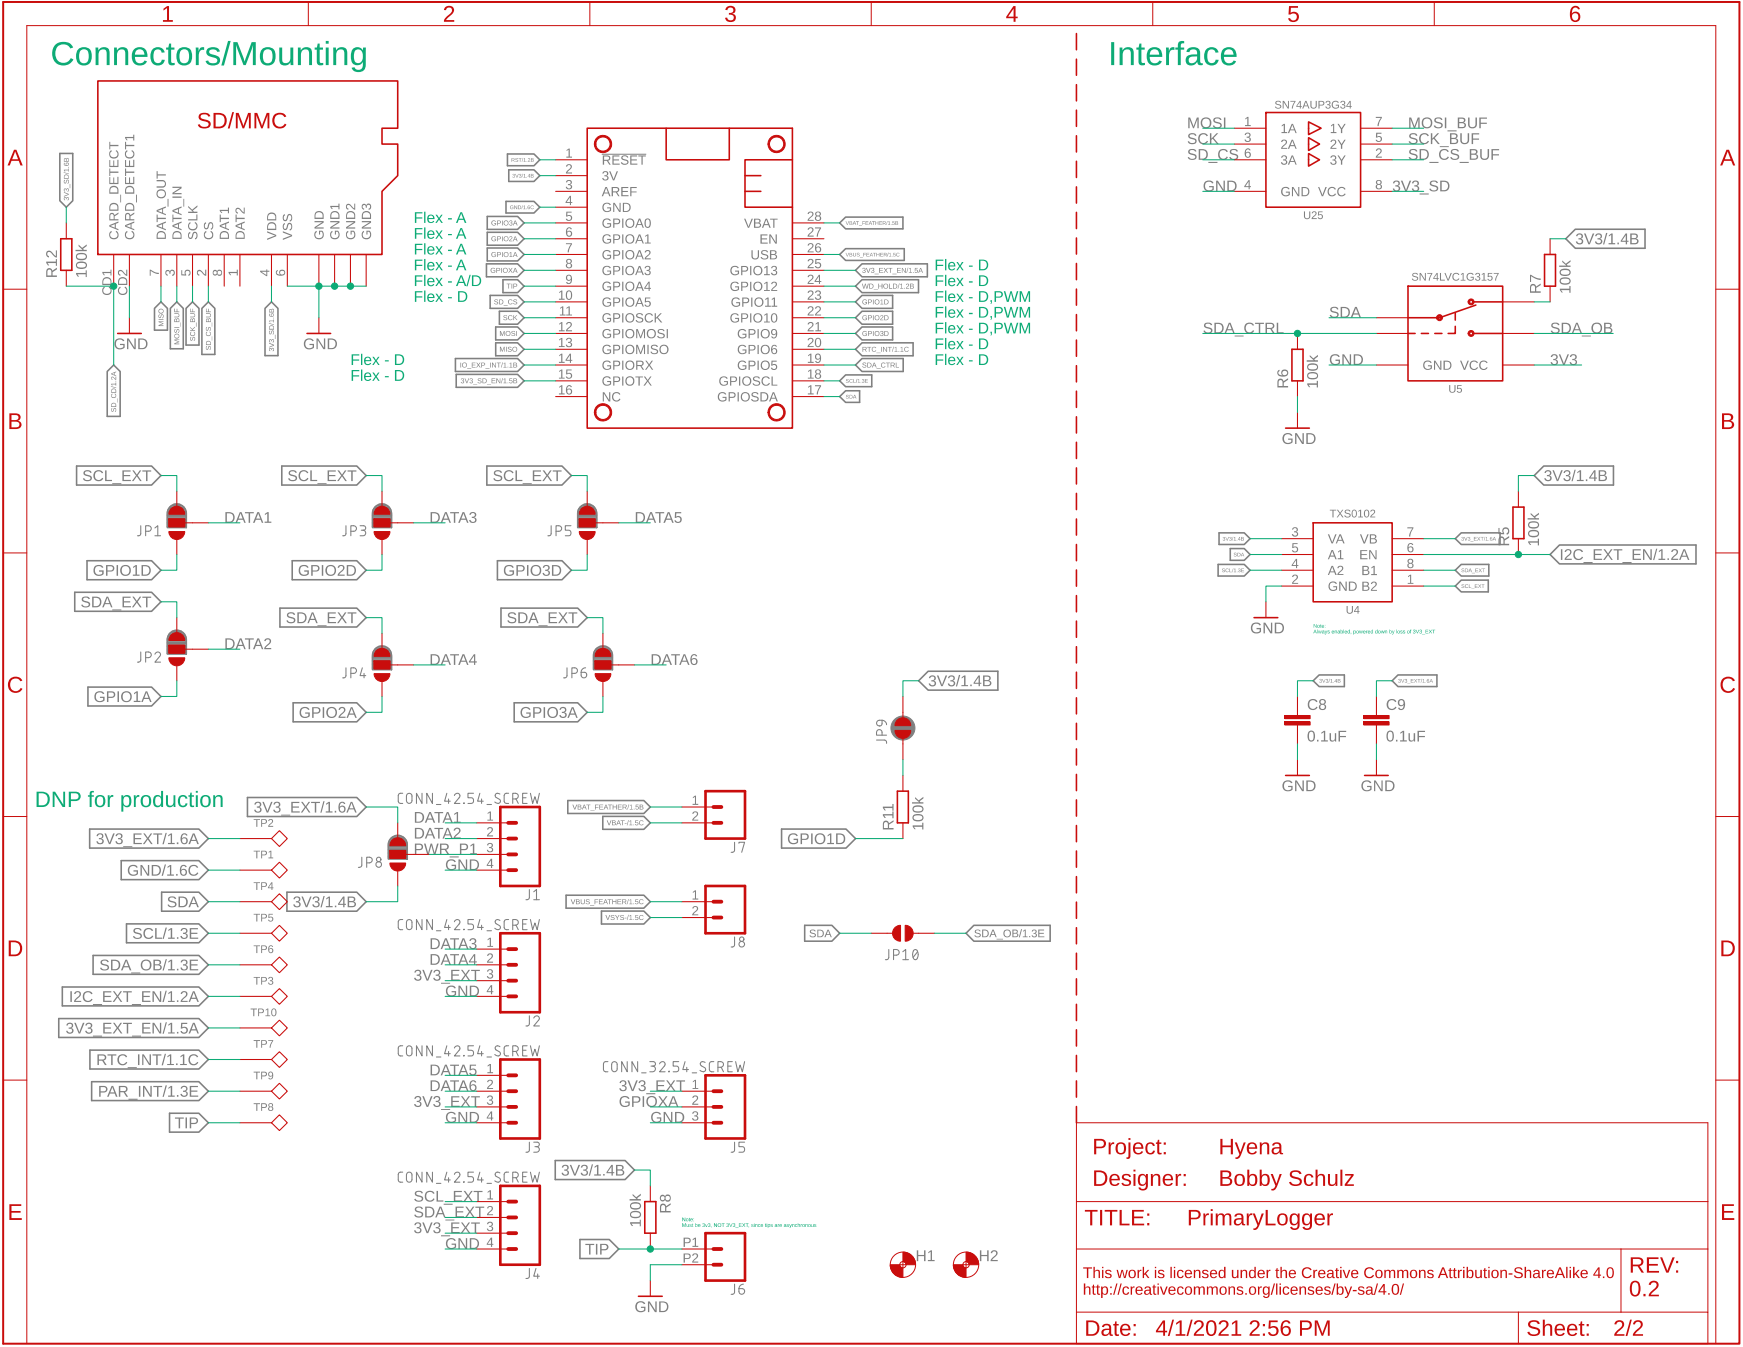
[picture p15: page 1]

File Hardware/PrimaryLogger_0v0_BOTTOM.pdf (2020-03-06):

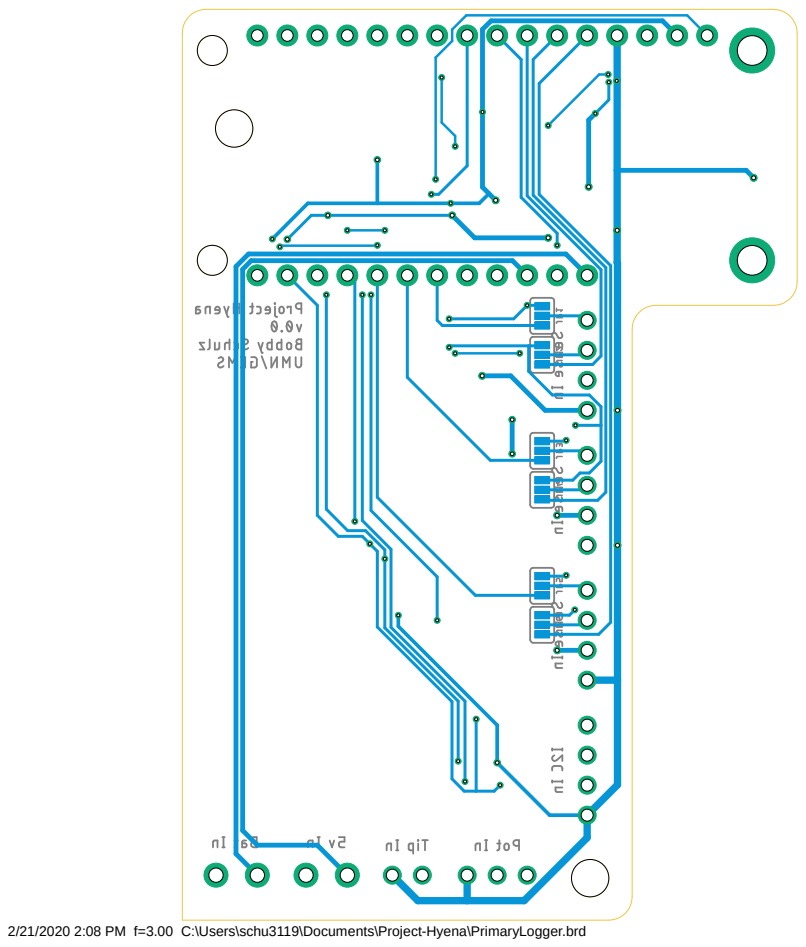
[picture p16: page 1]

2/21/2020 2:08 PM f=3.00 C:\Users\schu3119\Documents\Project-Hyena\PrimaryLogger.brd

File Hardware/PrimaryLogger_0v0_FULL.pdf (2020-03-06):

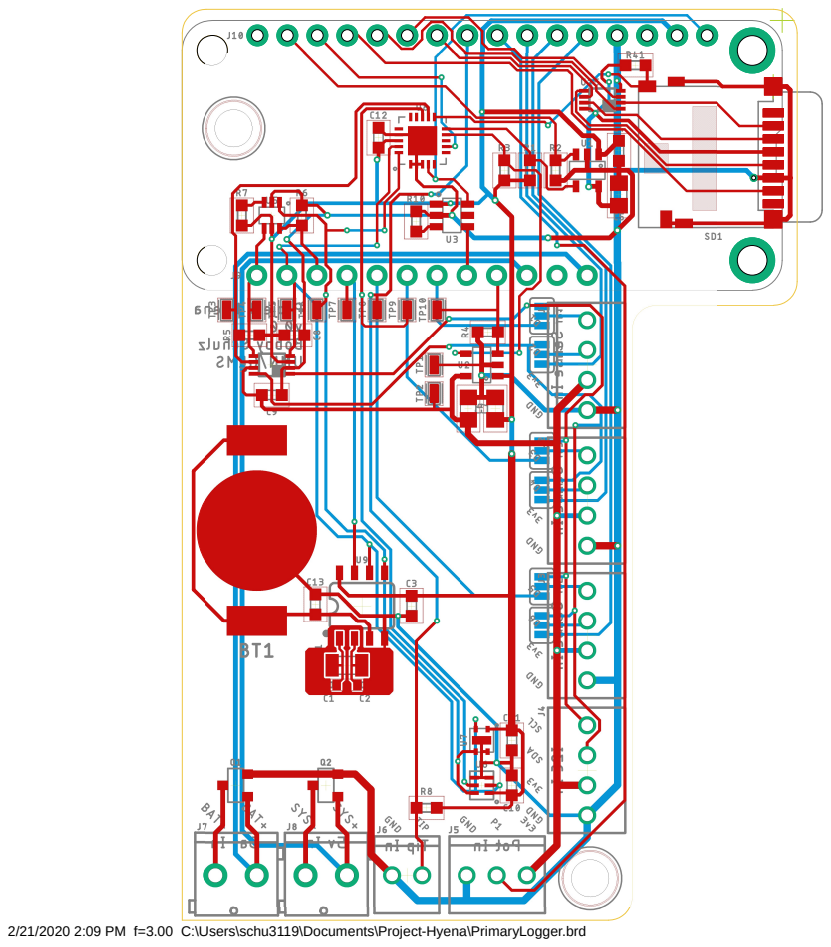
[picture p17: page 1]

2/21/2020 2:09 PM f=3.00 C:\Users\schu3119\Documents\Project-Hyena\PrimaryLogger.brd

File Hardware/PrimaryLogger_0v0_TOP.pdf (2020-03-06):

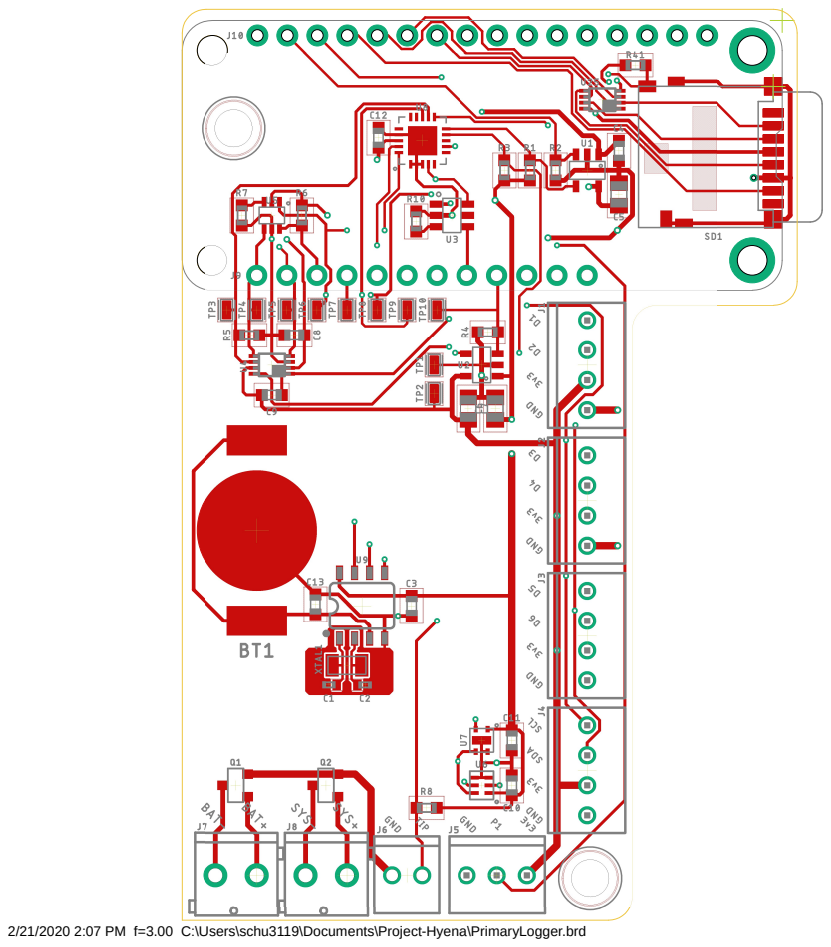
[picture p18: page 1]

2/21/2020 2:07 PM f=3.00 C:\Users\schu3119\Documents\Project-Hyena\PrimaryLogger.brd

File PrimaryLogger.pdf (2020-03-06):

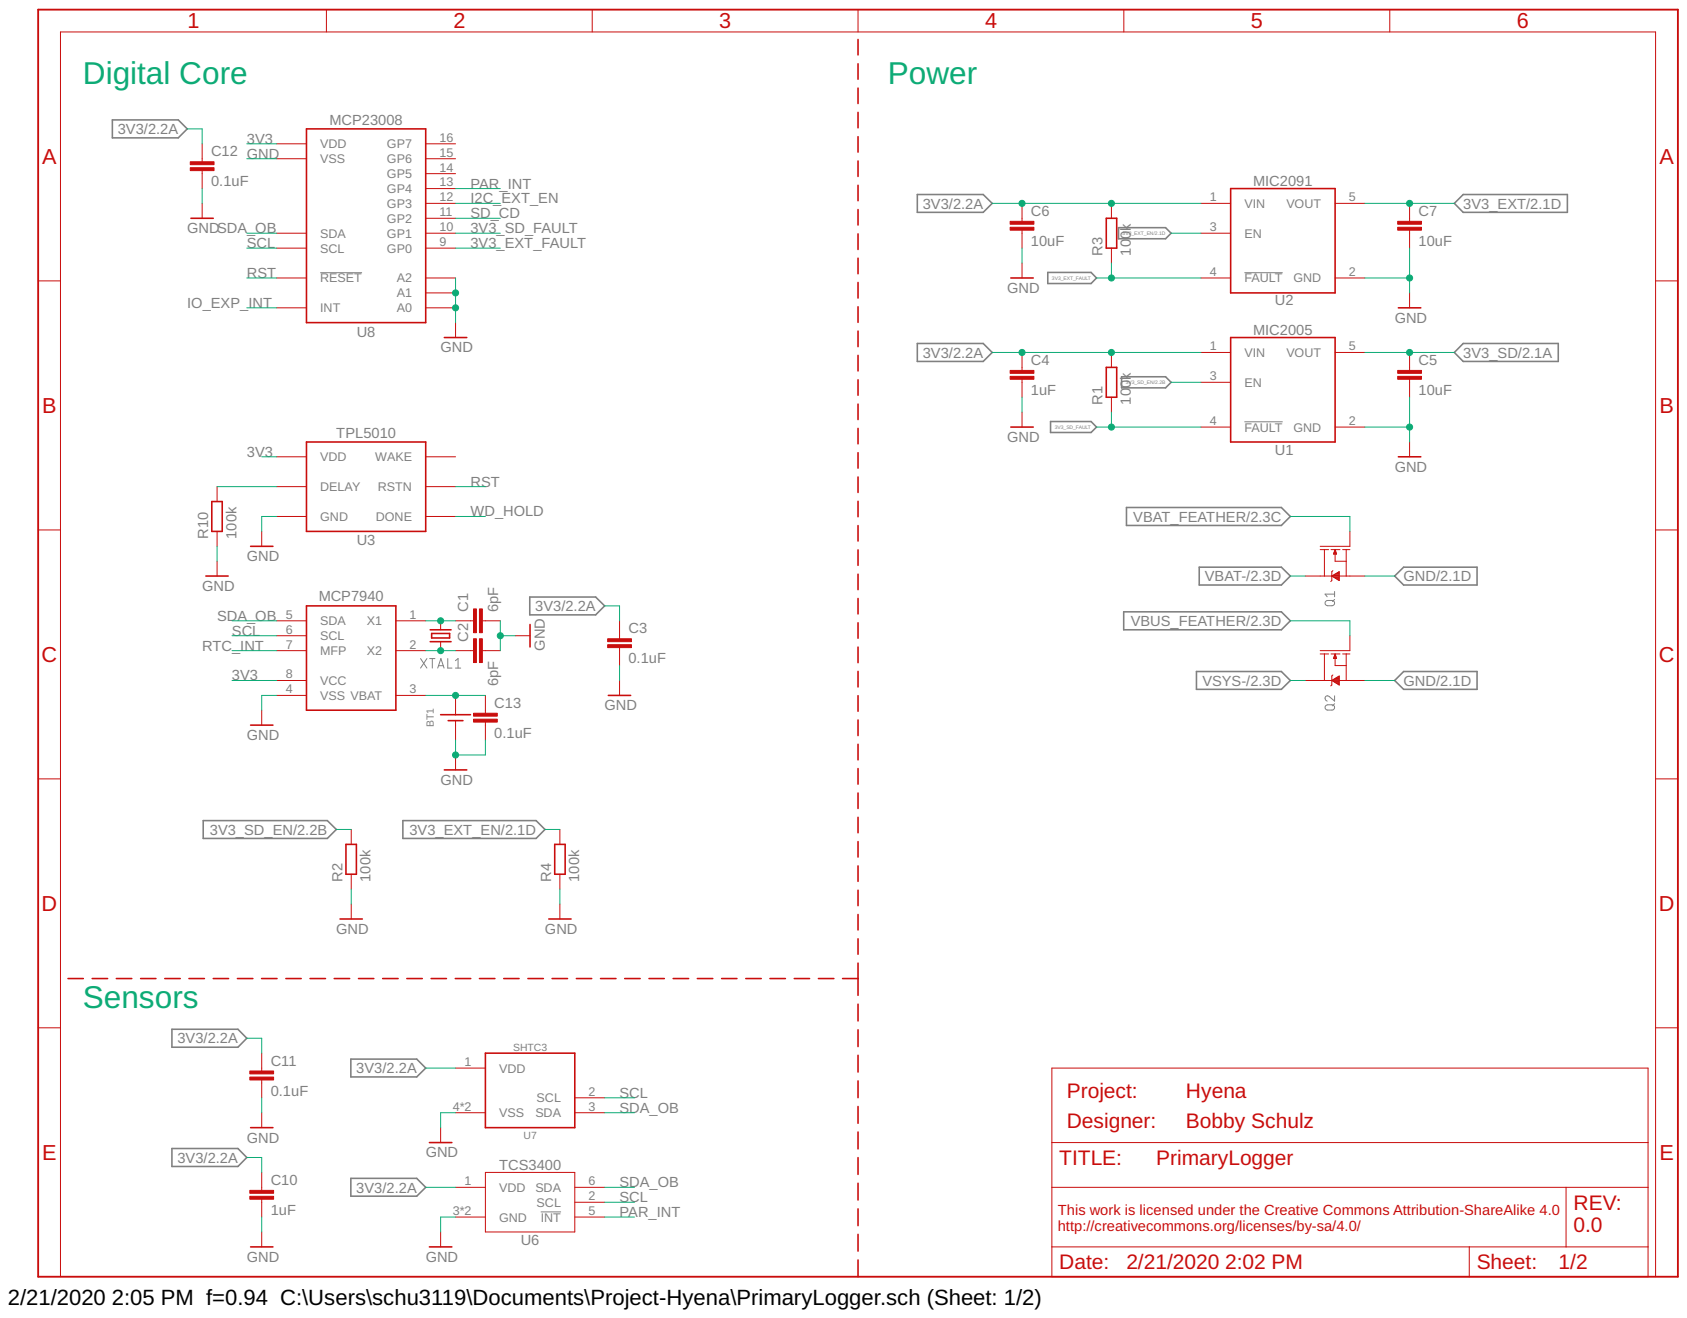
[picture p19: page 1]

This work is licensed under the Creative Commons Attribution-ShareAlike 4.0 http://creativecommons.org/licenses/by-sa/4.0/ | REV: 0.0

Date: 2/21/2020 2:02 PM | Sheet: 1/2

2/21/2020 2:05 PM f=0.94 C:\Users\schu3119\Documents\Project-Hyena\PrimaryLogger.sch (Sheet: 1/2)

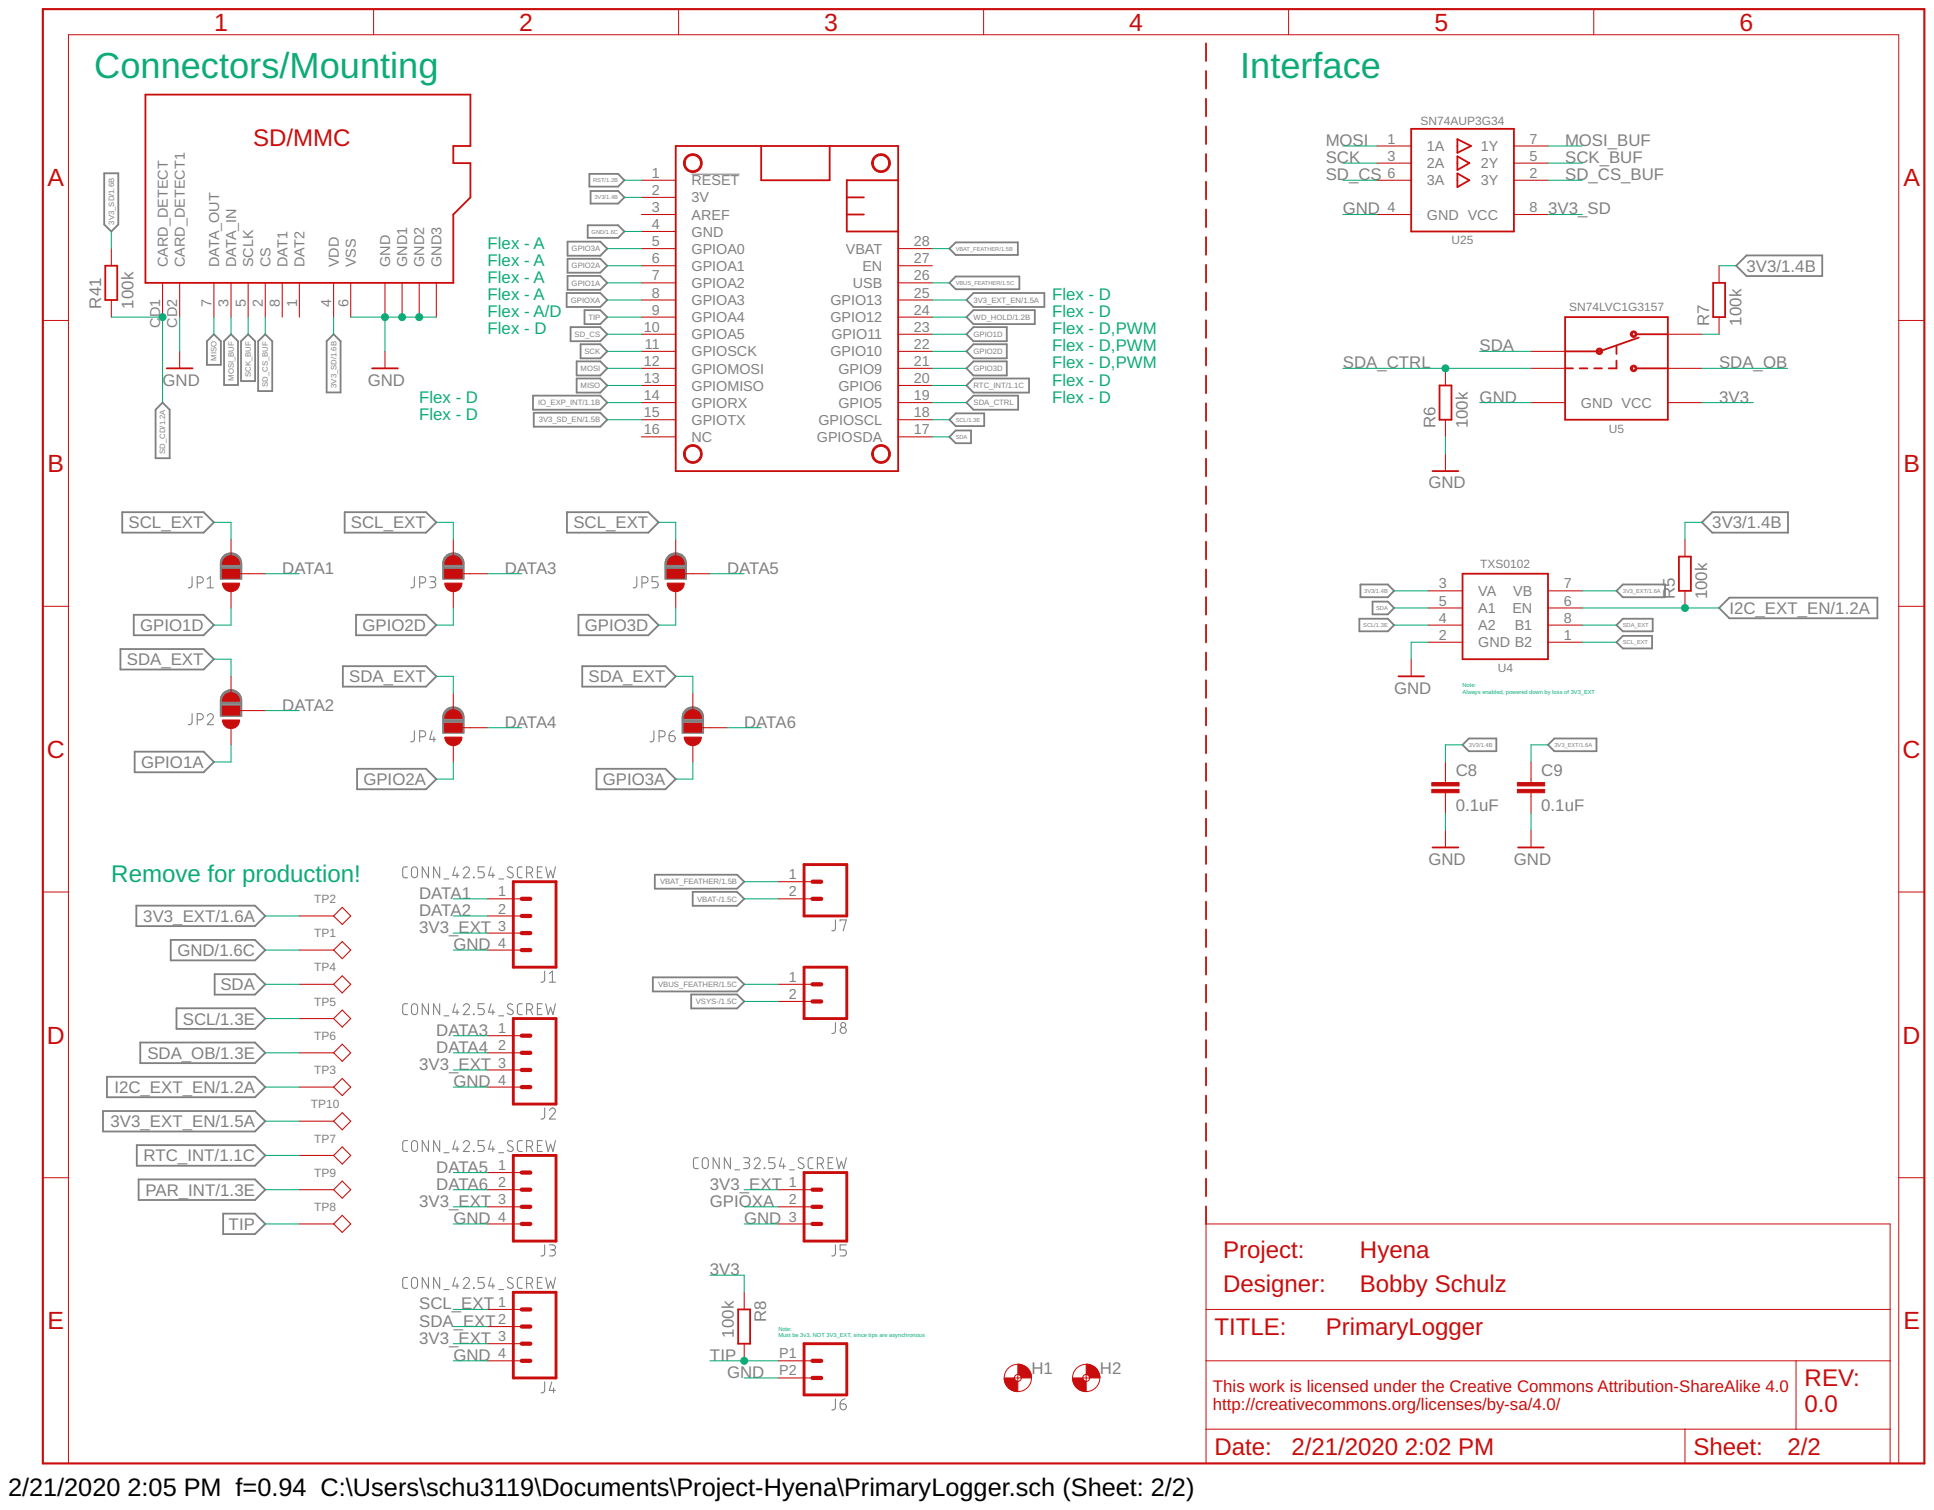
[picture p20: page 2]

Note: Always enabled, powered down by loss of 3V3_EXT

Note: Must be 3v3, NOT 3V3_EXT, since tips are asynchronous

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

2/21/2020 2:05 PM f=0.94 C:\Users\schu3119\Documents\Project-Hyena\PrimaryLogger.sch (Sheet: 2/2)

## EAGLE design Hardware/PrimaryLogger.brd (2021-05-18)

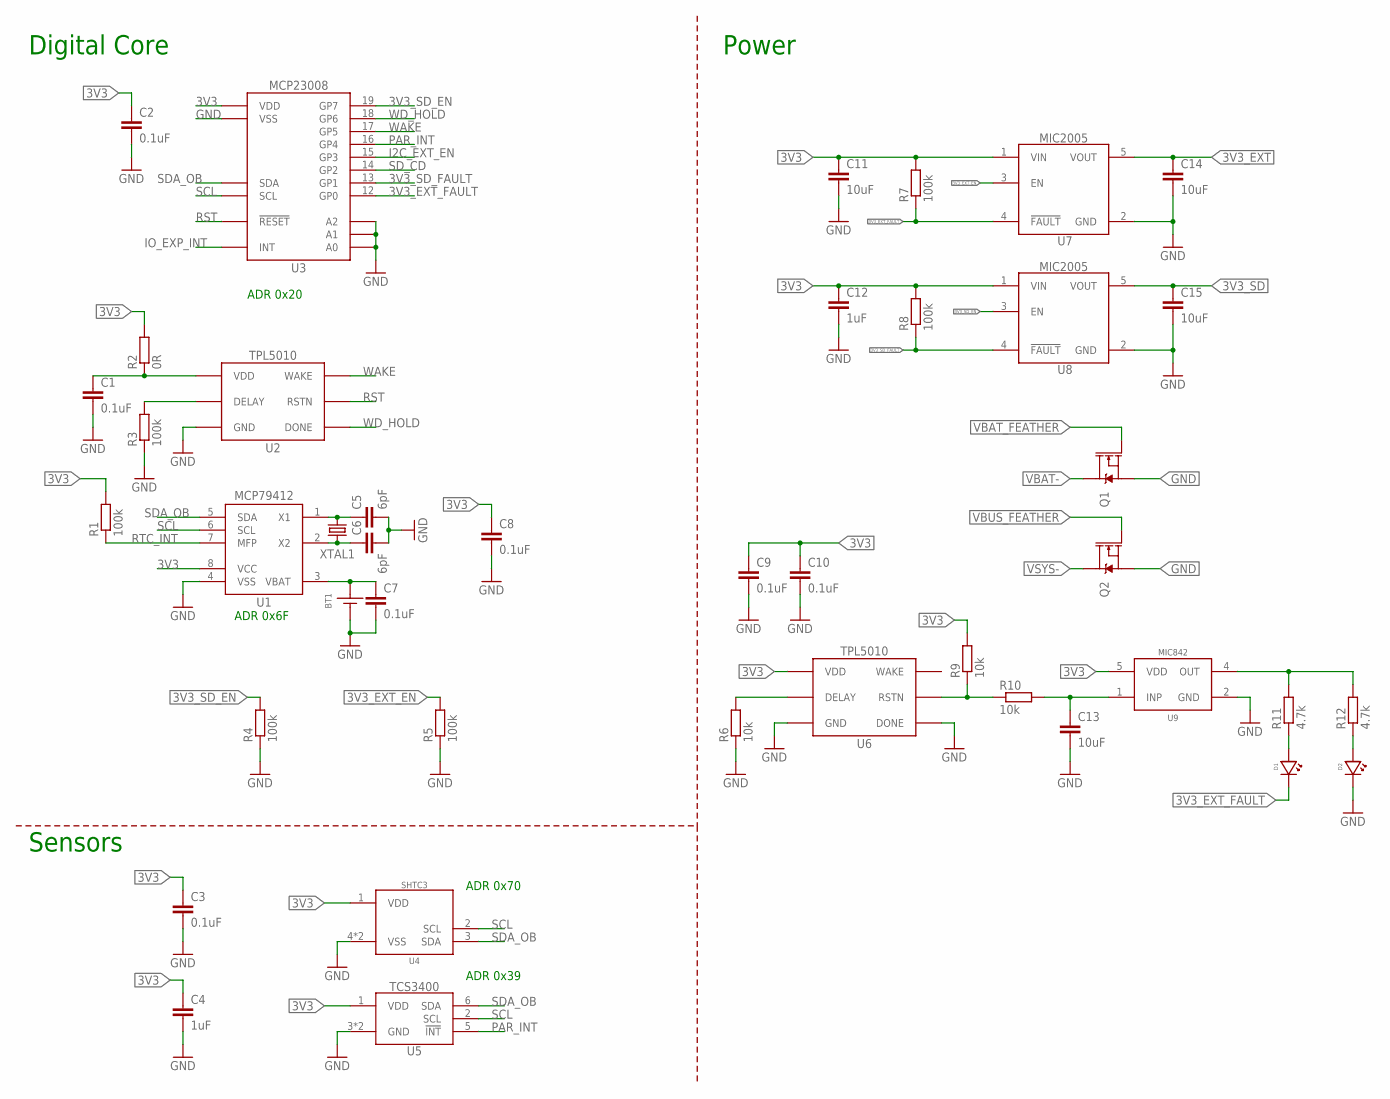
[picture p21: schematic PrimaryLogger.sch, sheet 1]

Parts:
BT1: BATTERY_COIN12MM; LINX_BAT-HLD-012-SMT
C1, C2, C3, C7, C8, C9, C10: 0.1uF; C0603
C4, C12: 1uF; C0603
C5, C6: 6pF; C0402
C11, C13, C14, C15: 10uF; C0805
D1: LEDRED0603; LED_0603
D2: LEDGREEN0603; LED_0603
Q1, Q2: DMG3404; SOT23-3
R1, R3, R4, R5, R7, R8: 100k; R0603
R2: 0R; R0603
R6, R9, R10: 10k; R0603
R11, R12: 4.7k; R0603
U1: MCP79412SOIC; SO08
U2, U6: TPL5010DDC; DDC_R-PDSO-G6
U3: MCP23008SSOP; SSOP20
U4: SHTC3DFN; DFN_4_2X2
U5: TCS3400
U7, U8: MIC2005; SOT23-5
U9: MIC842L; DCK_R-PDSO-G5
XTAL1: CRYSTAL3.2X1.5; CRYSTAL_3.2X1.5_2-SMD; MPN Abracon; DIGIKEY 535-11937-1-ND

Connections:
3V3: C2.1, C3.1, C4.1, C8.1, C9.1, C10.1, C11.1, C12.1, R1.2, R2.2, R7.2, R8.2, R9.2, U1.8 (VCC), U3.20 (VDD), U4.1 (VDD), U5.1 (VDD), U6.1 (VDD), U7.1 (VIN), U8.1 (VIN), U9.5 (VDD); also elsewhere on the board
3V3_EXT: C14.1, U7.5 (VOUT); also elsewhere on the board
3V3_EXT_EN: R5.2, U7.3 (EN); also elsewhere on the board
3V3_EXT_FAULT: D1.CATHODE, R7.1, U3.12 (GP0), U7.4 (!FAULT)
3V3_SD: C15.1, U8.5 (VOUT); also elsewhere on the board
3V3_SD_EN: R4.2, U3.19 (GP7), U8.3 (EN)
3V3_SD_FAULT: R8.1, U3.13 (GP1), U8.4 (!FAULT)
GND: BT1.GND (-), C1.2, C2.2, C3.2, C4.2, C5.2, C6.2, C7.2, C8.2, C9.2, C10.2, C11.2, C12.2, C13.2, C14.2, C15.2, D2.CATHODE, Q1.2 (S), Q2.2 (S), R3.1, R4.1, R5.1, R6.1, U1.4 (VSS), U2.2 (GND), U3.3 (A2), U3.4 (A1), U3.5 (A0), U3.9 (VSS), U4.4 (VSS), U4.EP (VSS), U5.3 (GND), U5.4 (GND), U6.2 (GND), U6.4 (DONE), U7.2 (GND), U8.2 (GND), U9.2 (GND); also elsewhere on the board
I2C_EXT_EN: U3.15 (GP3); also elsewhere on the board
IO_EXP_INT: U3.8 (INT); also elsewhere on the board
unnamed: C5.1, U1.1 (X1), XTAL1.P$1 (1)
unnamed: C6.1, U1.2 (X2), XTAL1.P$2 (2)
unnamed: R3.2, U2.3 (DELAY)
unnamed: C1.1, R2.1, U2.1 (VDD)
unnamed: R6.2, U6.3 (DELAY)
unnamed: C13.1, R10.2, U9.1 (INP)
unnamed: R9.1, R10.1, U6.6 (RSTN)
unnamed: R11.2, R12.2, U9.4 (OUT)
unnamed: D1.ANODE, R11.1
unnamed: D2.ANODE, R12.1
PAR_INT: U3.16 (GP4), U5.5 (!INT); also elsewhere on the board
RST: U2.6 (RSTN), U3.6 (!RESET); also elsewhere on the board
RTC_INT: R1.1, U1.7 (MFP); also elsewhere on the board
SCL: U1.6 (SCL), U3.1 (SCL), U4.2 (SCL), U5.2 (SCL); also elsewhere on the board
SDA_OB: U1.5 (SDA), U3.2 (SDA), U4.3 (SDA), U5.6 (SDA); also elsewhere on the board
SD_CD: U3.14 (GP2); also elsewhere on the board
VBAT: BT1.POWER0 (+), BT1.POWER1 (+), C7.1, U1.3 (VBAT)
VBAT-: Q1.3 (D); also elsewhere on the board
VBAT_FEATHER: Q1.1 (G); also elsewhere on the board
VBUS_FEATHER: Q2.1 (G); also elsewhere on the board
VSYS-: Q2.3 (D); also elsewhere on the board
WAKE: U2.5 (WAKE), U3.17 (GP5)
WD_HOLD: U2.4 (DONE), U3.18 (GP6)

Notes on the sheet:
Digital Core
Sensors
Power
ADR 0x39
ADR 0x70
ADR 0x6F
ADR 0x20

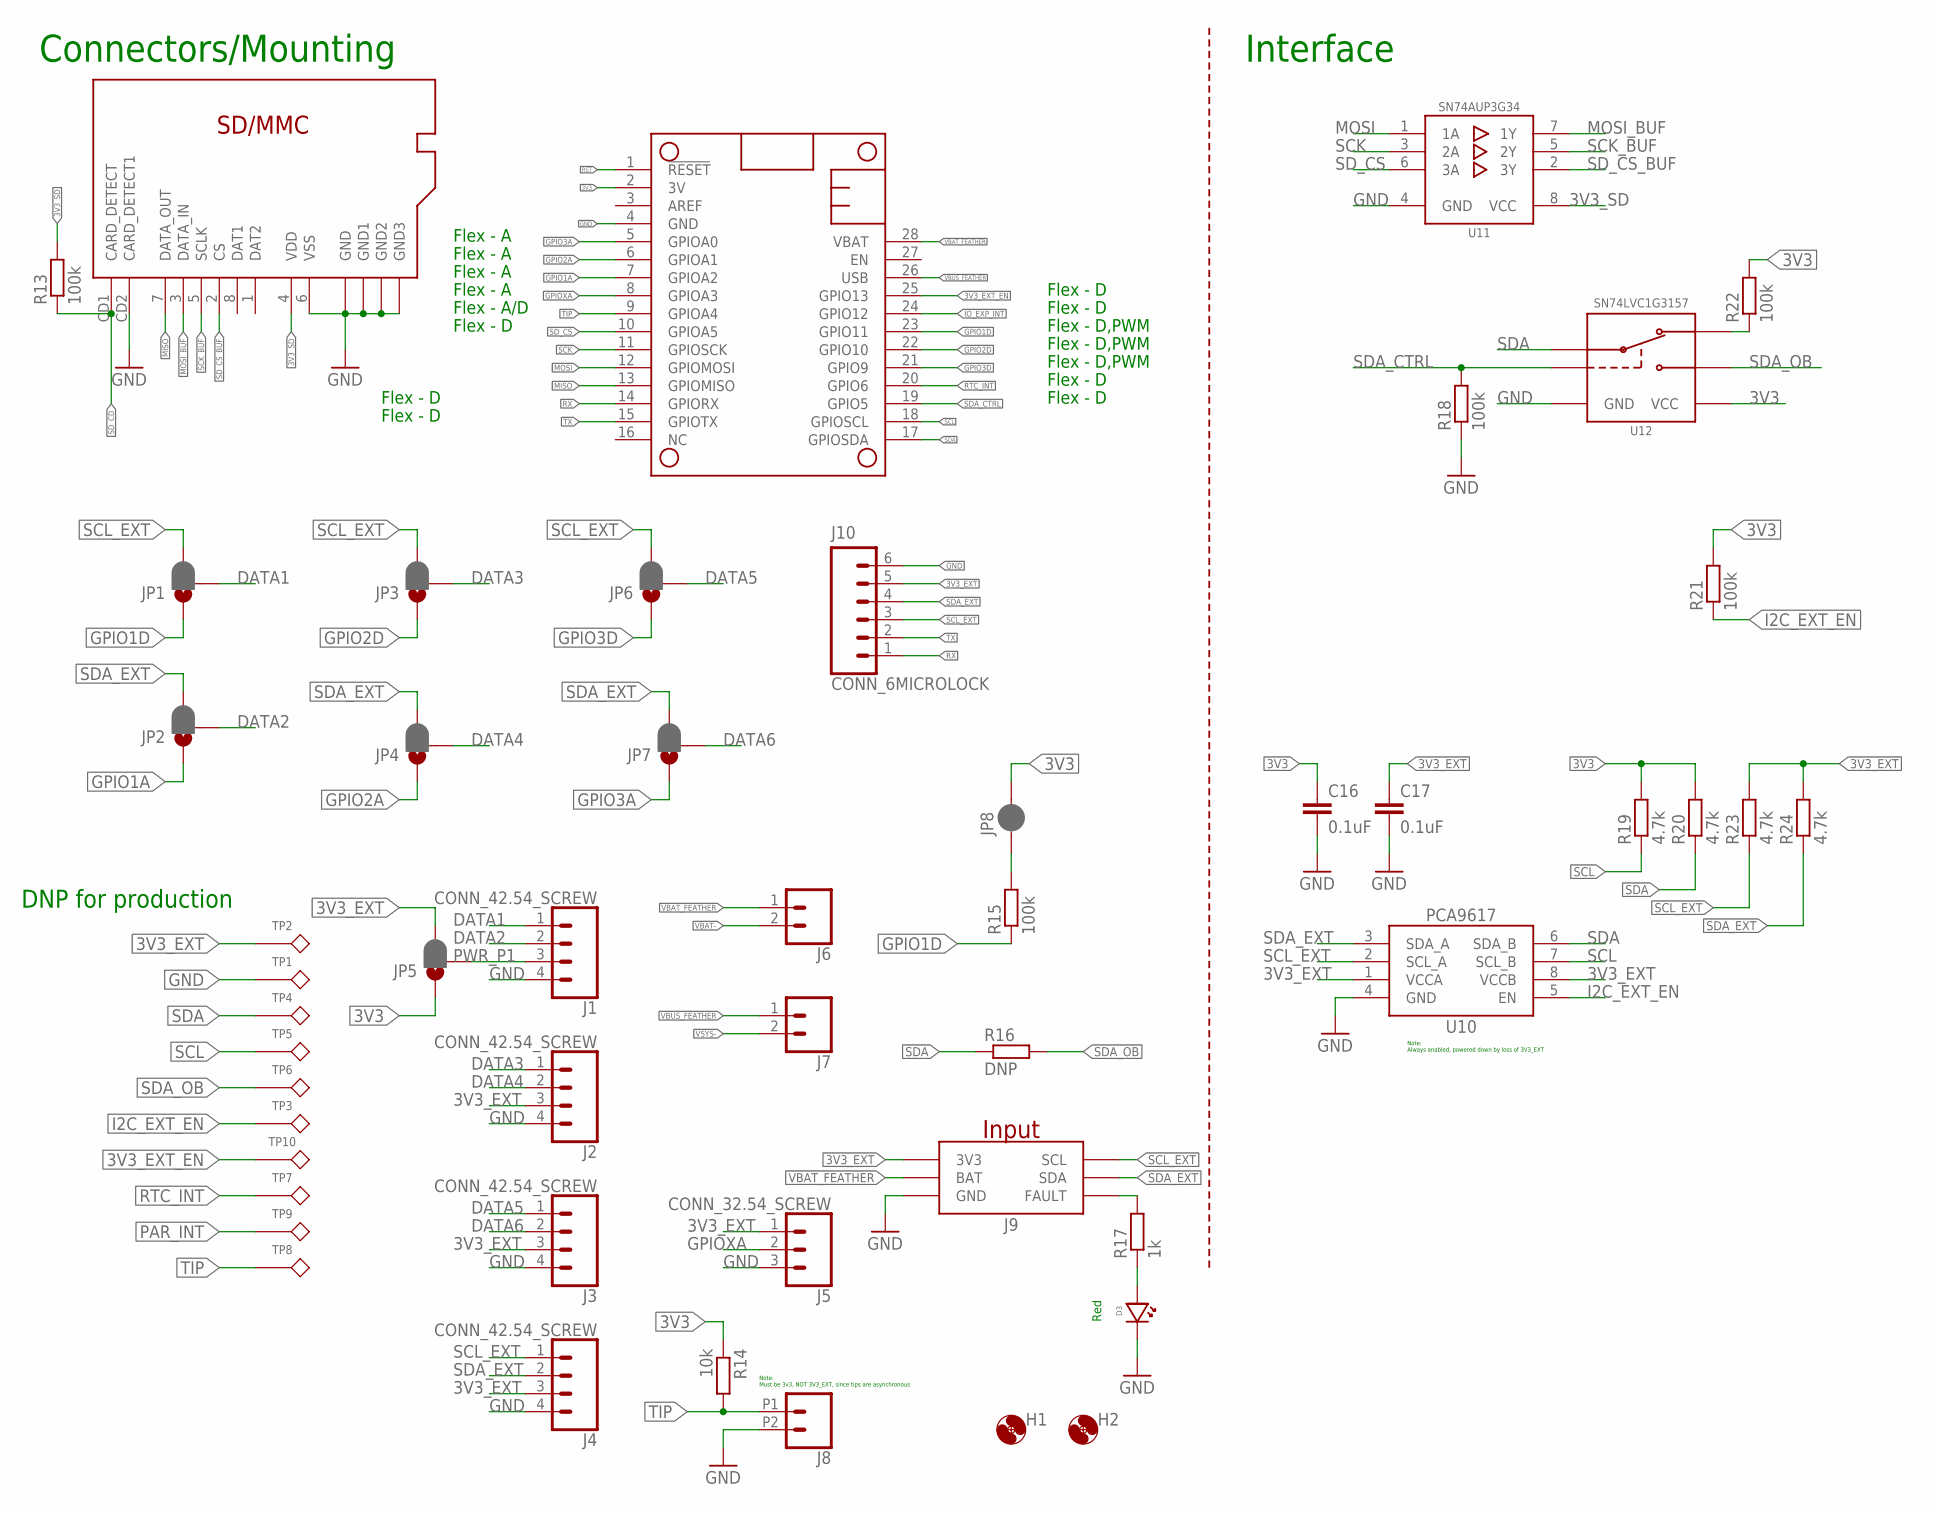
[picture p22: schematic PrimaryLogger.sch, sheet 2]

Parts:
C16, C17: 0.1uF; C0603
D3: LEDRED0603; LED_0603
H1, H2: MOUNTING_HOLE2_NP; 2_56
J1, J2, J3, J4: CONN_42.54_SCREW; 1X04_SCREW
J5: CONN_32.54_SCREW; 1X03_SCREW
J6, J7: CONN_023.5MM_ROUND; SCREWTERMINAL-3.5MM-2_ROUND
J8: CONN_022.54_SCREW_ROUND; 1X02_2.54_SCREWTERM_ROUND
J9: GEMS_POWER_PLUGINPUT; 2X3_MICROFIT_RT
J10: CONN_6MICROLOCK; 1X06_MICROLOCKPLUS
JP1, JP2, JP3, JP4, JP5, JP6, JP7: JUMPER-SMT_3_1-NC_PASTE_SILK; SMT-JUMPER_3_1-NC_PASTE_SILK
JP8: JUMPER-SMT_2_NC_PASTE_SILK; SMT-JUMPER_2_NC_PASTE_SILK
MS1: FEATHERWINGLAYOUT; FEATHERWING_MIN
R13, R15, R18, R21, R22: 100k; R0603
R14: 10k; R0603
R16: DNP; R0603
R17: 1k; R0603
R19, R20, R23, R24: 4.7k; R0603
SD1: MICRO_SD; CUSTOM-PARTS_SD_MICRO
TP1, TP2, TP3, TP4, TP5, TP6, TP7, TP8, TP9, TP10: TESTPOINTRCU; TESTPOINT_0603
U10: PCA9617; TSSOP_8
U11: SN74AUP3G34DCU; DCU_(R-PDSO-G8)
U12: SN74LVC1G3157SC70; DCK_R-PDSO-G6

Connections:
3V3: C16.1, JP5.1, JP8.2, MS1.2 (3V), R14.1, R19.2, R20.2, R21.2, R22.2, U12.5 (VCC); also elsewhere on the board
3V3_EXT: C17.1, J2.3, J3.3, J4.3, J5.1, J9.5 (3V3), J10.5, JP5.3, R23.2, R24.2, TP2.1, U10.1 (VCCA), U10.8 (VCCB); also elsewhere on the board
3V3_EXT_EN: MS1.25 (GPIO13), TP10.1; also elsewhere on the board
3V3_SD: R13.2, SD1.4 (VDD), U11.8 (VCC); also elsewhere on the board
DATA1: J1.1, JP1.2
DATA2: J1.2, JP2.2
DATA3: J2.1, JP3.2
DATA4: J2.2, JP4.2
DATA5: J3.1, JP6.2
DATA6: J3.2, JP7.2
GND: C16.2, C17.2, D3.CATHODE, J1.4, J2.4, J3.4, J4.4, J5.3, J8.P2 (2), J9.2 (GND), J10.6, MS1.4 (GND), R18.1, SD1.6 (VSS), SD1.CD2 (CARD_DETECT1), SD1.GND@1 (GND), SD1.GND@2 (GND1), SD1.GND@3 (GND2), SD1.GND@5 (GND3), TP1.1, U10.4 (GND), U11.4 (GND), U12.2 (GND); also elsewhere on the board
GPIO1A: JP2.1, MS1.7 (GPIOA2)
GPIO1D: JP1.1, MS1.23 (GPIO11), R15.1
GPIO2A: JP4.1, MS1.6 (GPIOA1)
GPIO2D: JP3.1, MS1.22 (GPIO10)
GPIO3A: JP7.1, MS1.5 (GPIOA0)
GPIO3D: JP6.1, MS1.21 (GPIO9)
GPIOXA: J5.2, MS1.8 (GPIOA3)
I2C_EXT_EN: R21.1, TP3.1, U10.5 (EN); also elsewhere on the board
IO_EXP_INT: MS1.24 (GPIO12); also elsewhere on the board
MISO: MS1.13 (GPIOMISO), SD1.7 (DATA_OUT)
MOSI: MS1.12 (GPIOMOSI), U11.1 (1A)
MOSI_BUF: SD1.3 (DATA_IN), U11.7 (1Y)
unnamed: R22.1, U12.3 (B1)
unnamed: JP8.1, R15.2
unnamed: J9.3 (FAULT), R17.2
unnamed: D3.ANODE, R17.1
PAR_INT: TP9.1; also elsewhere on the board
PWR_P1: J1.3, JP5.2
RST: MS1.1 (!RESET); also elsewhere on the board
RTC_INT: MS1.20 (GPIO6), TP7.1; also elsewhere on the board
RX: J10.1, MS1.14 (GPIORX)
SCK: MS1.11 (GPIOSCK), U11.3 (2A)
SCK_BUF: SD1.5 (SCLK), U11.5 (2Y)
SCL: MS1.18 (GPIOSCL), R19.1, TP5.1, U10.7 (SCL_B); also elsewhere on the board
SCL_EXT: J4.1, J9.6 (SCL), J10.3, JP1.3, JP3.3, JP6.3, R23.1, U10.2 (SCL_A)
SDA: MS1.17 (GPIOSDA), R16.1, R20.1, TP4.1, U10.6 (SDA_B), U12.4 (A)
SDA_CTRL: MS1.19 (GPIO5), R18.2, U12.6 (S)
SDA_EXT: J4.2, J9.4 (SDA), J10.4, JP2.3, JP4.3, JP7.3, R24.1, U10.3 (SDA_A)
SDA_OB: R16.2, TP6.1, U12.1 (B2); also elsewhere on the board
SD_CD: R13.1, SD1.CD1 (CARD_DETECT); also elsewhere on the board
SD_CS: MS1.10 (GPIOA5), U11.6 (3A)
SD_CS_BUF: SD1.2 (CS), U11.2 (3Y)
TIP: J8.P1 (1), MS1.9 (GPIOA4), R14.2, TP8.1
TX: J10.2, MS1.15 (GPIOTX)
VBAT-: J6.2; also elsewhere on the board
VBAT_FEATHER: J6.1, J9.1 (BAT), MS1.28 (VBAT); also elsewhere on the board
VBUS_FEATHER: J7.1, MS1.26 (USB); also elsewhere on the board
VSYS-: J7.2; also elsewhere on the board

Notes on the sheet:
Note: Must be 3v3, NOT 3V3_EXT, since tips are asynchronous
DNP for production
Flex - A
Flex - A/D
Flex - D
Flex - D,PWM
Note: Always enabled, powered down by loss of 3V3_EXT
Connectors/Mounting
Interface
Red

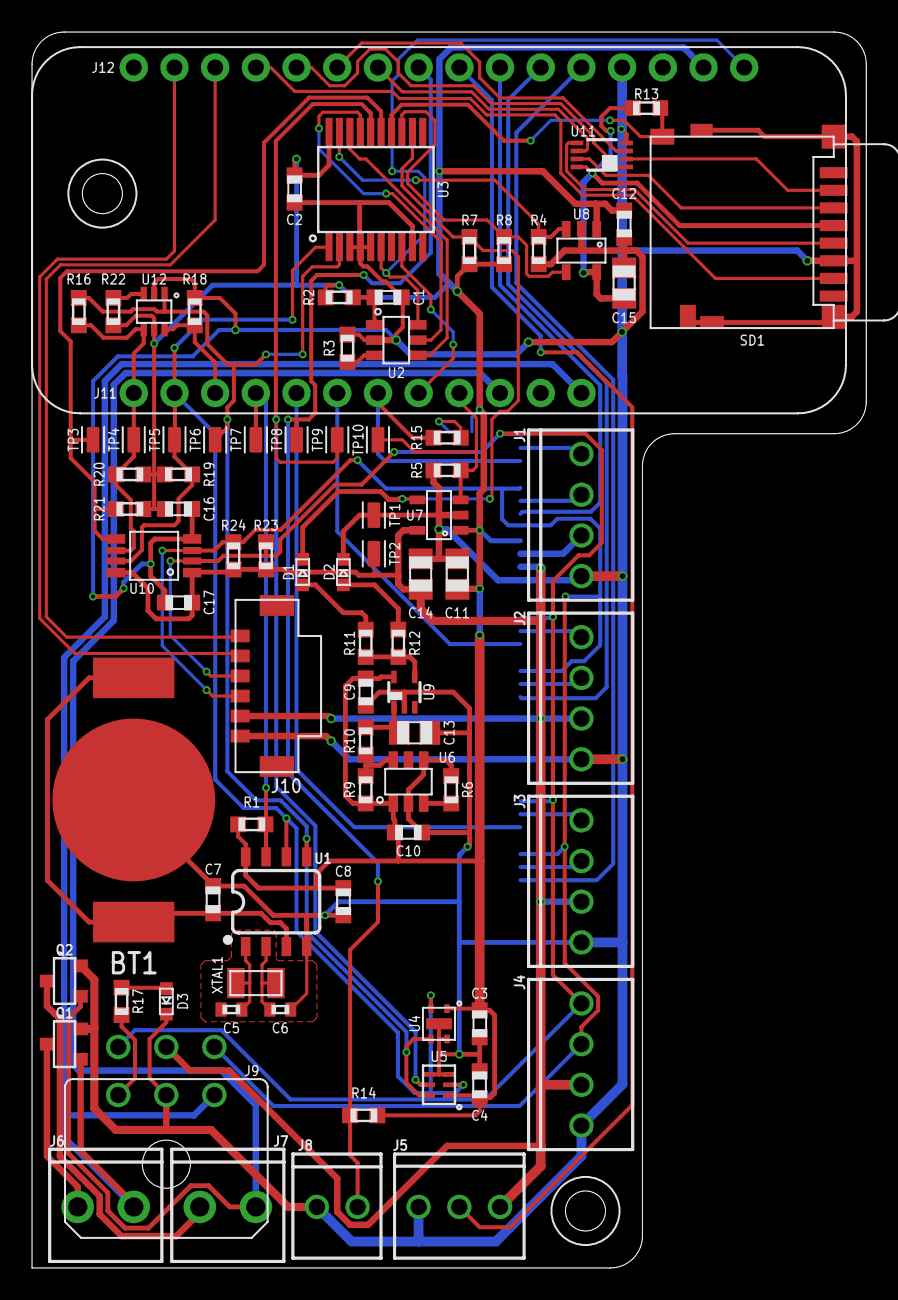
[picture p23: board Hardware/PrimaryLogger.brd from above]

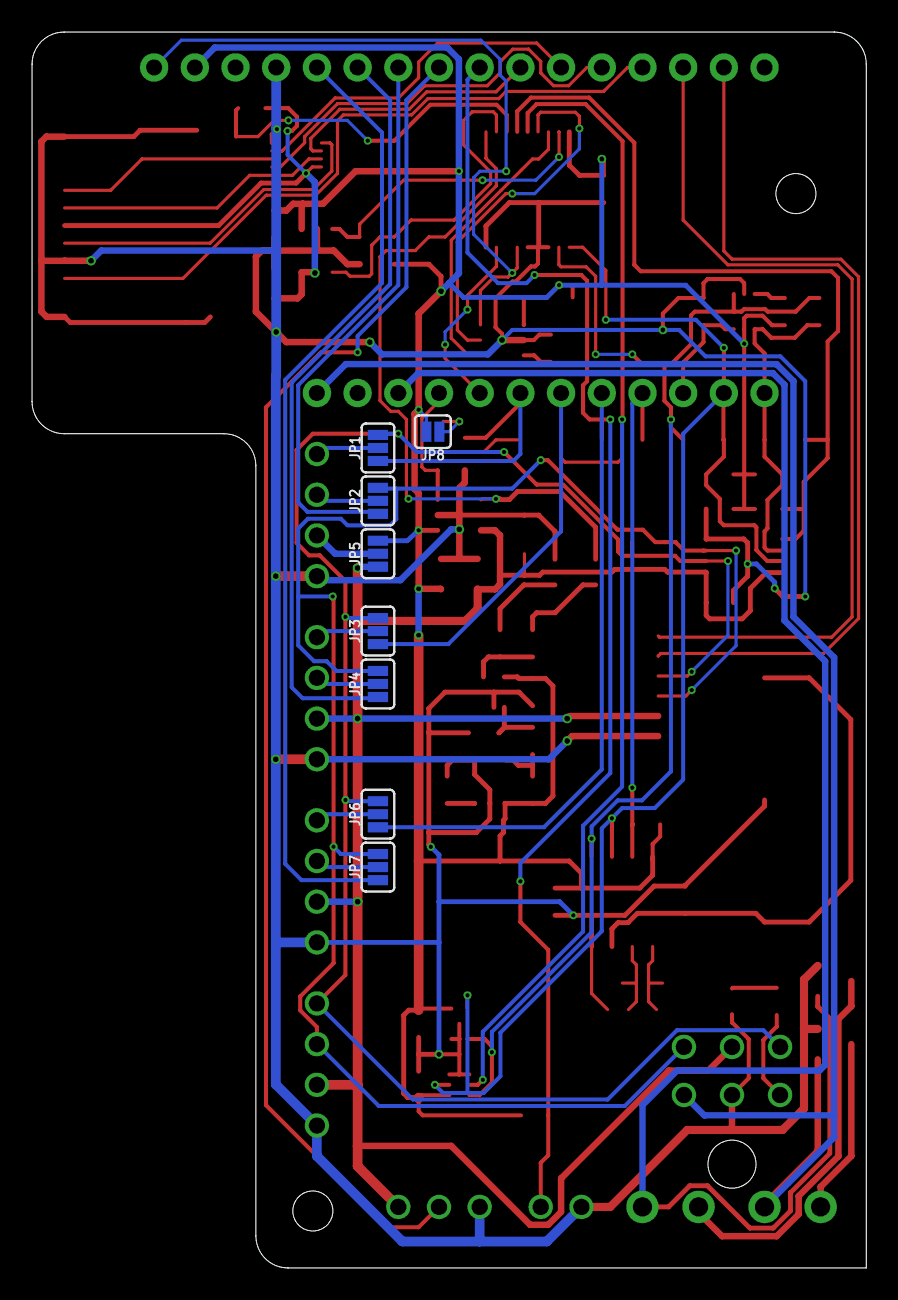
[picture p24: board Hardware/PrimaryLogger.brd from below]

Board: 2 copper layers, 52.1 x 77.1 mm, 92 parts (8 on the bottom side), 65 nets.

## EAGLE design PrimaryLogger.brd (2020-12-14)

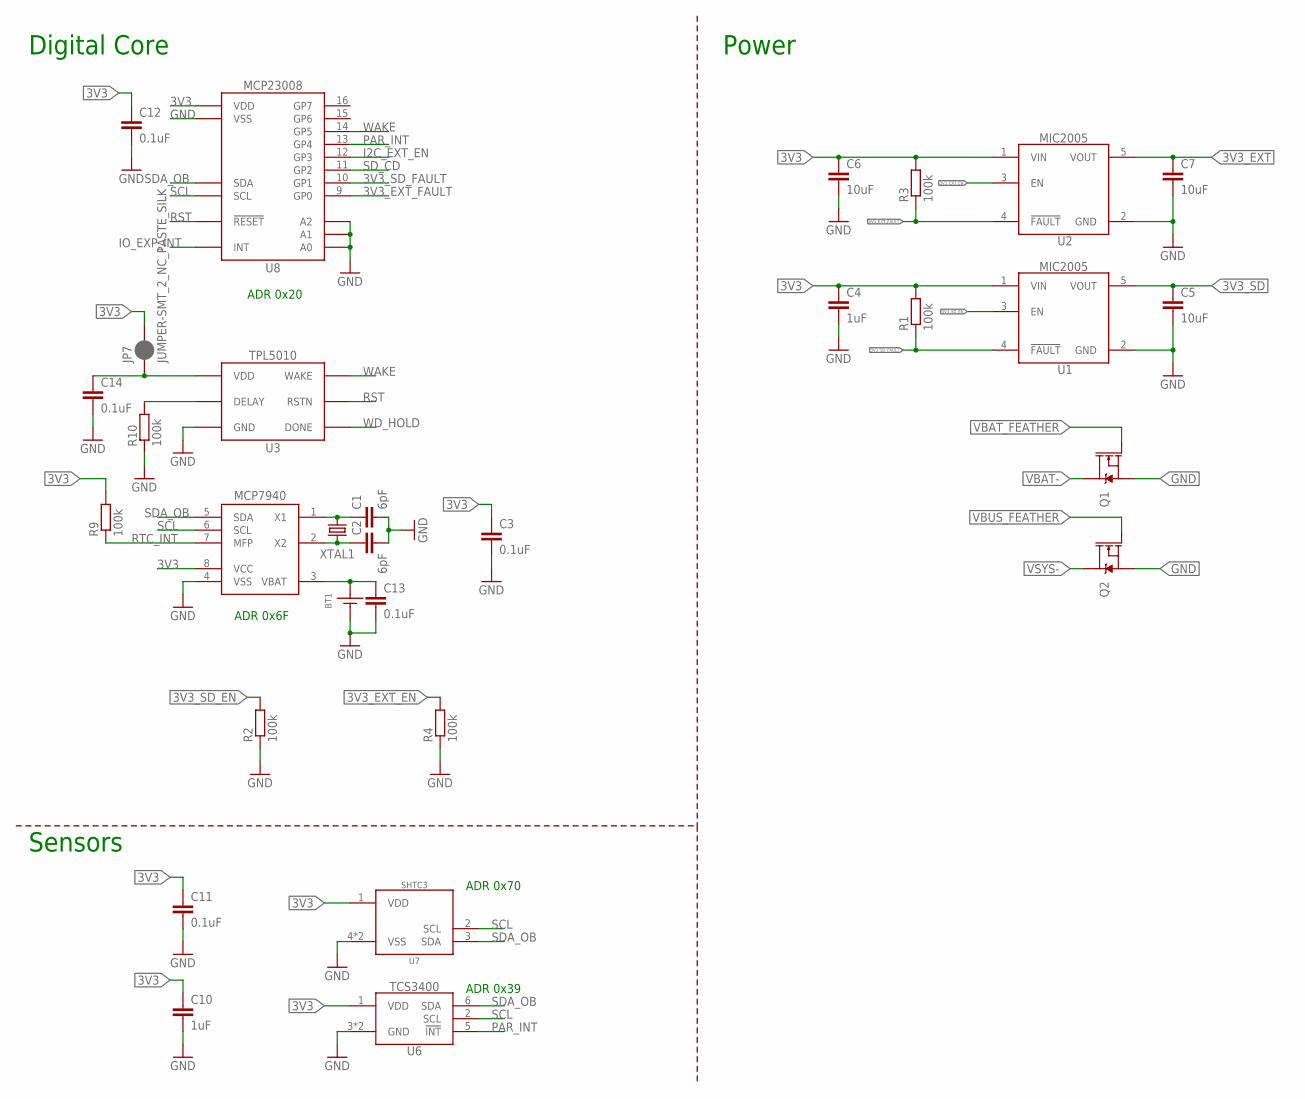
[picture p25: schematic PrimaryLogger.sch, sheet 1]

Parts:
BT1: BATTERY_COIN12MM; LINX_BAT-HLD-012-SMT
C1, C2: 6pF; C0402
C3, C11, C12, C13, C14: 0.1uF; C0603
C4, C10: 1uF; C0603
C5, C6, C7: 10uF; C0805
JP7: JUMPER-SMT_2_NC_PASTE_SILK; SMT-JUMPER_2_NC_PASTE_SILK
Q1, Q2: DMG3404; SOT23-3
R1, R2, R3, R4, R9, R10: 100k; R0603
U1, U2: MIC2005; SOT23-5
U3: TPL5010DDC; DDC_R-PDSO-G6
U6: TCS3400
U7: SHTC3DFN; DFN_4_2X2
U8: MCP23008QFN; QFN20
U9: MCP7940SOIC; SO08
XTAL1: CRYSTAL3.2X1.5; CRYSTAL_3.2X1.5_2-SMD; MPN Abracon; DIGIKEY 535-11937-1-ND

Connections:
3V3: C3.1, C4.1, C6.1, C10.1, C11.1, C12.1, JP7.2, R1.2, R3.2, R9.2, U1.1 (VIN), U2.1 (VIN), U6.1 (VDD), U7.1 (VDD), U8.18 (VDD), U9.8 (VCC); also elsewhere on the board
3V3_EXT: C7.1, U2.5 (VOUT); also elsewhere on the board
3V3_EXT_EN: R4.2, U2.3 (EN); also elsewhere on the board
3V3_EXT_FAULT: R3.1, U2.4 (!FAULT), U8.9 (GP0)
3V3_SD: C5.1, U1.5 (VOUT); also elsewhere on the board
3V3_SD_EN: R2.2, U1.3 (EN); also elsewhere on the board
3V3_SD_FAULT: R1.1, U1.4 (!FAULT), U8.10 (GP1)
GND: BT1.GND (-), C1.2, C2.2, C3.2, C4.2, C5.2, C6.2, C7.2, C10.2, C11.2, C12.2, C13.2, C14.2, Q1.2 (S), Q2.2 (S), R2.1, R4.1, R10.1, U1.2 (GND), U2.2 (GND), U3.2 (GND), U6.3 (GND), U6.4 (GND), U7.4 (VSS), U7.EP (VSS), U8.1 (A2), U8.2 (A1), U8.3 (A0), U8.17 (VSS), U8.EP (VSS), U9.4 (VSS); also elsewhere on the board
I2C_EXT_EN: U8.12 (GP3); also elsewhere on the board
IO_EXP_INT: U8.7 (INT); also elsewhere on the board
unnamed: C1.1, U9.1 (X1), XTAL1.P$1 (1)
unnamed: C2.1, U9.2 (X2), XTAL1.P$2 (2)
unnamed: R10.2, U3.3 (DELAY)
unnamed: C14.1, JP7.1, U3.1 (VDD)
PAR_INT: U6.5 (!INT), U8.13 (GP4); also elsewhere on the board
RST: U3.6 (RSTN), U8.4 (!RESET); also elsewhere on the board
RTC_INT: R9.1, U9.7 (MFP); also elsewhere on the board
SCL: U6.2 (SCL), U7.2 (SCL), U8.19 (SCL), U9.6 (SCL); also elsewhere on the board
SDA_OB: U6.6 (SDA), U7.3 (SDA), U8.20 (SDA), U9.5 (SDA); also elsewhere on the board
SD_CD: U8.11 (GP2); also elsewhere on the board
VBAT: BT1.POWER0 (+), BT1.POWER1 (+), C13.1, U9.3 (VBAT)
VBAT-: Q1.3 (D); also elsewhere on the board
VBAT_FEATHER: Q1.1 (G); also elsewhere on the board
VBUS_FEATHER: Q2.1 (G); also elsewhere on the board
VSYS-: Q2.3 (D); also elsewhere on the board
WAKE: U3.5 (WAKE), U8.14 (GP5)
WD_HOLD: U3.4 (DONE); also elsewhere on the board

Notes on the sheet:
Digital Core
Sensors
Power
ADR 0x39
ADR 0x70
ADR 0x6F
ADR 0x20

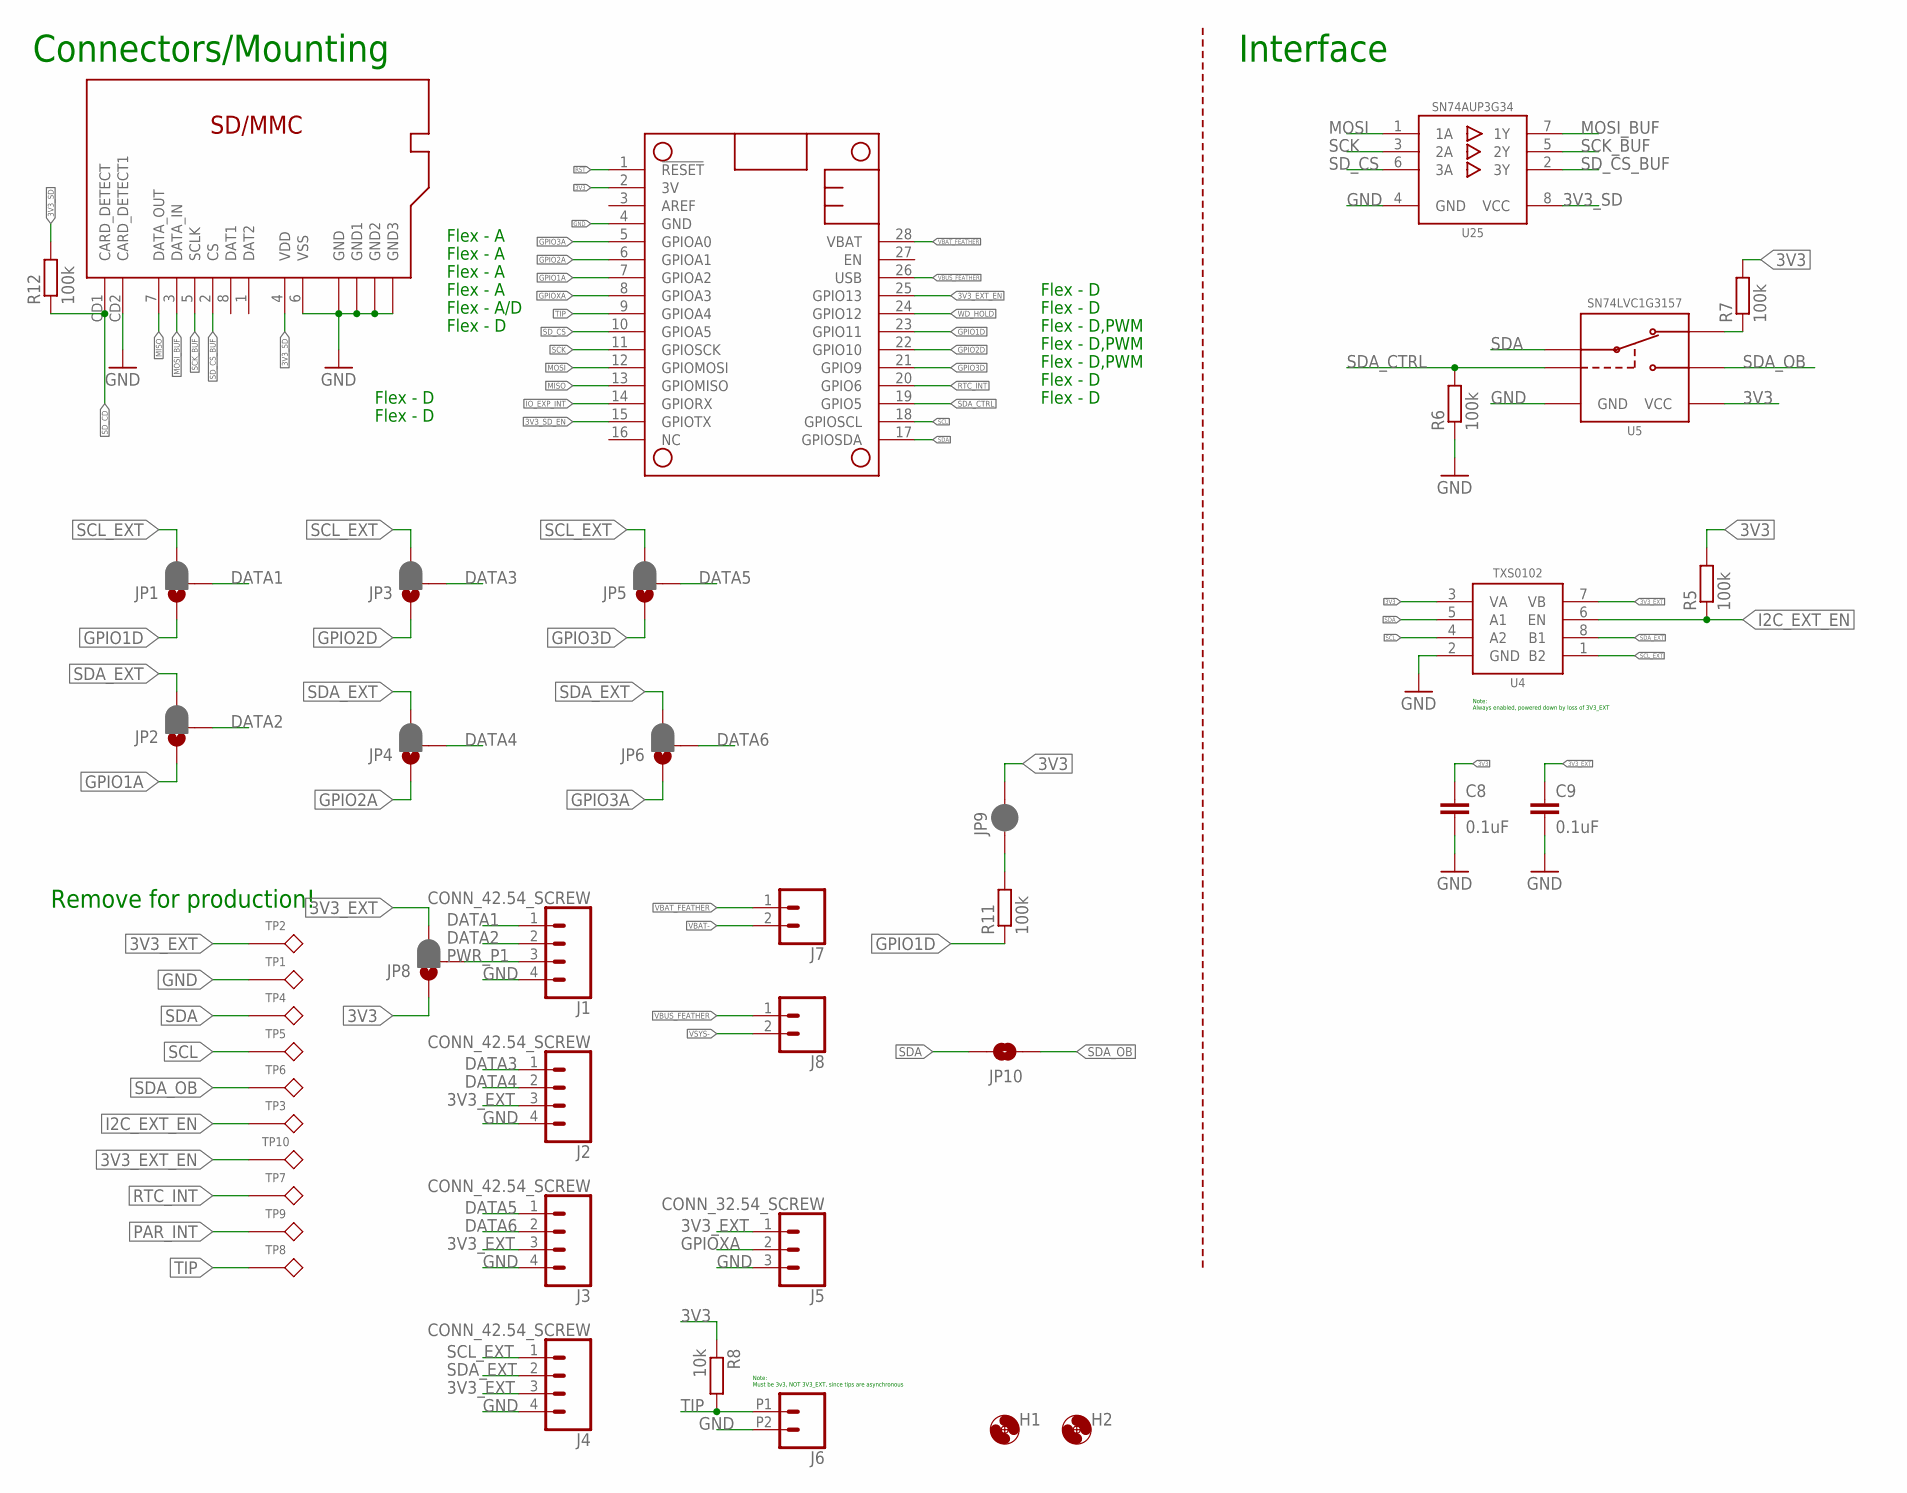
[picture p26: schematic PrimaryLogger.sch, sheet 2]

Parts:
C8, C9: 0.1uF; C0603
H1, H2: MOUNTING_HOLE4_NP; 4_40
J1, J2, J3, J4: CONN_42.54_SCREW; 1X04_SCREW
J5: CONN_32.54_SCREW; 1X03_SCREW
J6: CONN_022.54_SCREW_ROUND; 1X02_2.54_SCREWTERM_ROUND
J7, J8: CONN_023.5MM_ROUND; SCREWTERMINAL-3.5MM-2_ROUND
JP1, JP2, JP3, JP4, JP5, JP6, JP8: JUMPER-SMT_3_1-NC_PASTE_SILK; SMT-JUMPER_3_1-NC_PASTE_SILK
JP9: JUMPER-SMT_2_NC_PASTE_SILK; SMT-JUMPER_2_NC_PASTE_SILK
JP10: JUMPER-SMT_2_NO_SILK; SMT-JUMPER_2_NO_SILK
MS1: FEATHERWING_NODIM; FEATHERWING_DIM
R5, R6, R7, R11, R12: 100k; R0603
R8: 10k; R0603
SD1: MICRO_SD; CUSTOM-PARTS_SD_MICRO
TP1, TP2, TP3, TP4, TP5, TP6, TP7, TP8, TP9, TP10: TESTPOINTRCU; TESTPOINT_0603
U4: TXS0102DCU; DCU_(R-PDSO-G8)
U5: SN74LVC1G3157SC70; DCK_R-PDSO-G6
U25: SN74AUP3G34DCU; DCU_(R-PDSO-G8)

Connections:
3V3: C8.1, JP8.1, JP9.2, MS1.2 (3V), R5.2, R7.2, R8.1, U4.3 (VA), U5.5 (VCC); also elsewhere on the board
3V3_EXT: C9.1, J2.3, J3.3, J4.3, J5.1, JP8.3, TP2.1, U4.7 (VB); also elsewhere on the board
3V3_EXT_EN: MS1.25 (GPIO13), TP10.1; also elsewhere on the board
3V3_SD: R12.2, SD1.4 (VDD), U25.8 (VCC); also elsewhere on the board
3V3_SD_EN: MS1.15 (GPIOTX); also elsewhere on the board
DATA1: J1.1, JP1.2
DATA2: J1.2, JP2.2
DATA3: J2.1, JP3.2
DATA4: J2.2, JP4.2
DATA5: J3.1, JP5.2
DATA6: J3.2, JP6.2
GND: C8.2, C9.2, J1.4, J2.4, J3.4, J4.4, J5.3, J6.P2 (2), MS1.4 (GND), R6.1, SD1.6 (VSS), SD1.CD2 (CARD_DETECT1), SD1.GND@1 (GND), SD1.GND@2 (GND1), SD1.GND@3 (GND2), SD1.GND@5 (GND3), TP1.1, U4.2 (GND), U5.2 (GND), U25.4 (GND); also elsewhere on the board
GPIO1A: JP2.1, MS1.7 (GPIOA2)
GPIO1D: JP1.1, MS1.23 (GPIO11), R11.1
GPIO2A: JP4.1, MS1.6 (GPIOA1)
GPIO2D: JP3.1, MS1.22 (GPIO10)
GPIO3A: JP6.1, MS1.5 (GPIOA0)
GPIO3D: JP5.1, MS1.21 (GPIO9)
GPIOXA: J5.2, MS1.8 (GPIOA3)
I2C_EXT_EN: R5.1, TP3.1, U4.6 (EN); also elsewhere on the board
IO_EXP_INT: MS1.14 (GPIORX); also elsewhere on the board
MISO: MS1.13 (GPIOMISO), SD1.7 (DATA_OUT)
MOSI: MS1.12 (GPIOMOSI), U25.1 (1A)
MOSI_BUF: SD1.3 (DATA_IN), U25.7 (1Y)
unnamed: R7.1, U5.3 (B1)
unnamed: JP9.1, R11.2
PAR_INT: TP9.1; also elsewhere on the board
PWR_P1: J1.3, JP8.2
RST: MS1.1 (!RESET); also elsewhere on the board
RTC_INT: MS1.20 (GPIO6), TP7.1; also elsewhere on the board
SCK: MS1.11 (GPIOSCK), U25.3 (2A)
SCK_BUF: SD1.5 (SCLK), U25.5 (2Y)
SCL: MS1.18 (GPIOSCL), TP5.1, U4.4 (A2); also elsewhere on the board
SCL_EXT: J4.1, JP1.3, JP3.3, JP5.3, U4.1 (B2)
SDA: JP10.2, MS1.17 (GPIOSDA), TP4.1, U4.5 (A1), U5.4 (A)
SDA_CTRL: MS1.19 (GPIO5), R6.2, U5.6 (S)
SDA_EXT: J4.2, JP2.3, JP4.3, JP6.3, U4.8 (B1)
SDA_OB: JP10.1, TP6.1, U5.1 (B2); also elsewhere on the board
SD_CD: R12.1, SD1.CD1 (CARD_DETECT); also elsewhere on the board
SD_CS: MS1.10 (GPIOA5), U25.6 (3A)
SD_CS_BUF: SD1.2 (CS), U25.2 (3Y)
TIP: J6.P1 (1), MS1.9 (GPIOA4), R8.2, TP8.1
VBAT-: J7.2; also elsewhere on the board
VBAT_FEATHER: J7.1, MS1.28 (VBAT); also elsewhere on the board
VBUS_FEATHER: J8.1, MS1.26 (USB); also elsewhere on the board
VSYS-: J8.2; also elsewhere on the board
WD_HOLD: MS1.24 (GPIO12); also elsewhere on the board

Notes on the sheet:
Note: Must be 3v3, NOT 3V3_EXT, since tips are asynchronous
Remove for production!
Flex - A
Flex - A/D
Flex - D
Flex - D,PWM
Note: Always enabled, powered down by loss of 3V3_EXT
Connectors/Mounting
Interface

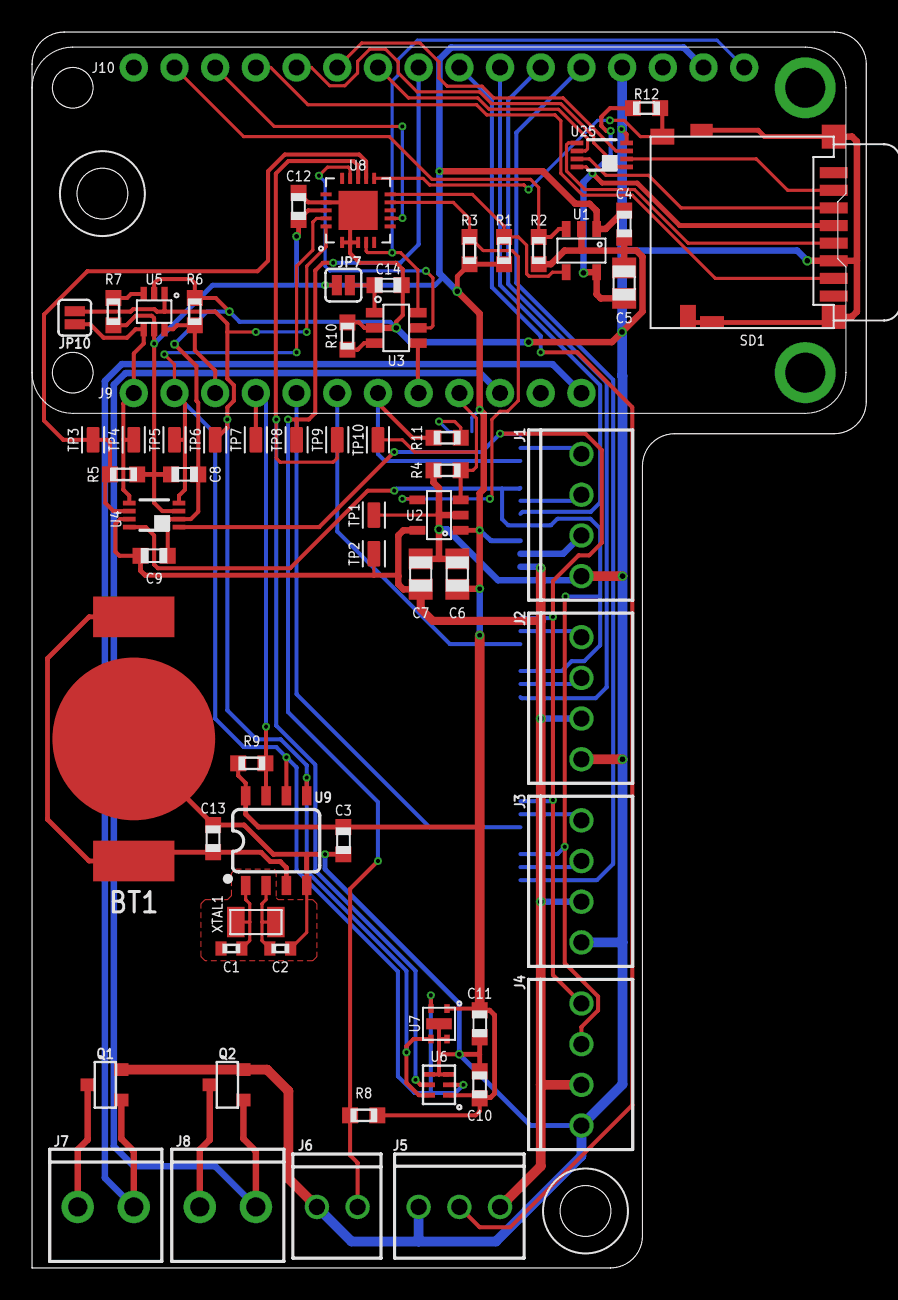
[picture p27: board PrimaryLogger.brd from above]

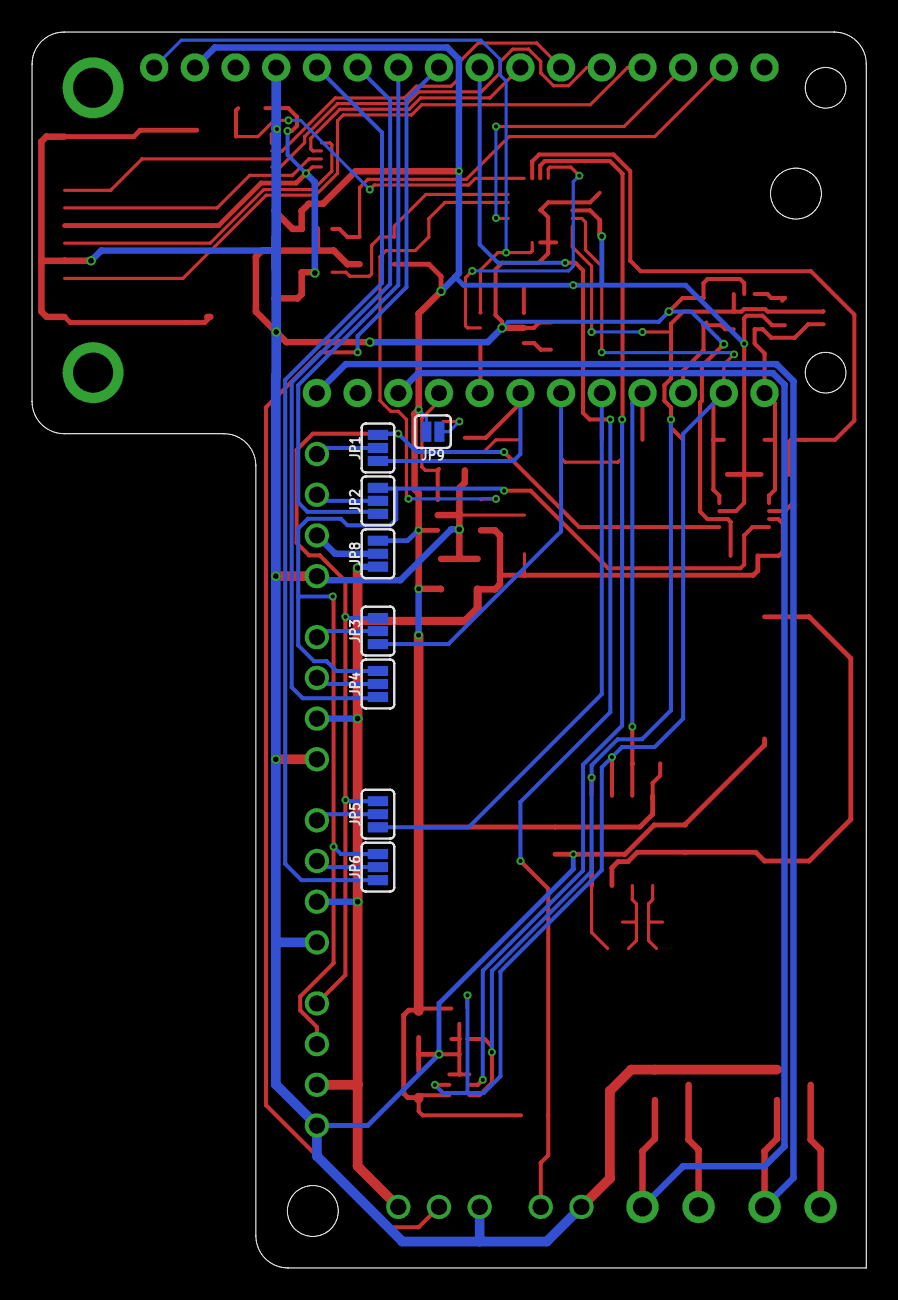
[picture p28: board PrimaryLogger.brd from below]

Board: 2 copper layers, 52.1 x 77.1 mm, 72 parts (8 on the bottom side), 55 nets.

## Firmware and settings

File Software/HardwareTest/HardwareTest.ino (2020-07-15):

#include <SPI.h>
#include <Wire.h>
#include <MCP7940.h>
#include <SD.h>
//FIX Make random function??

boolean Debug = false; //FIX!!
char ReadArray[25] = {0};

// namespace Pins { //Use for Boron
// 	constexpr uint16_t WD_HOLD  = 7;
// 	constexpr uint16_t EXT_EN   = 8;
// 	constexpr uint16_t SD_EN    = 9;
// 	constexpr uint16_t SD_CS    = 14;
// 	constexpr uint16_t SDA_CTRL = 2;
// 	constexpr uint16_t TIP      = 15;
// 	constexpr uint16_t GPIOXA 	= 16;
// 	constexpr uint16_t Clock_INT 	= 2;
// }

namespace Pins { //Use for Feather M0 Express
	constexpr uint16_t WD_HOLD  = 12;
	constexpr uint16_t EXT_EN   = 13;
	constexpr uint16_t SD_EN    = 1;
	constexpr uint16_t SD_CS    = 19;
	constexpr uint16_t SDA_CTRL = 5;
	constexpr uint16_t TIP      = 18;
	constexpr uint16_t GPIOXA 	= 17;
	constexpr uint16_t Clock_INT 	= 6;
}

//////////////////////////////////////I2C/////////////////////////////////////
uint8_t ExpectedAddresses[] = {0x20, 0x39, 0x6F, 0x70}; //Define the I2C devices which should be present on Hyena 
uint8_t NumDevices = 4; //This is the number of I2C devices expected 

////////////////////////////////////SD////////////////////////////////////////
char FileNameC[11]; //Used for file handling
boolean SD_Init = false;

////////////////////////////////////CLOCK//////////////////////////////////////
MCP7940 Clock; // Instantiate Clock

void setup() {
	Serial.begin(115200); //Begin fast serial 
	pinMode(Pins::EXT_EN, OUTPUT);
	digitalWrite(Pins::EXT_EN, HIGH); //Turn on external power 
	while(!Serial); //Wait for serial to start //DEBUG!
	Wire.begin(); //Start I2C module
  

}

void loop() {
	Serial.println("Begin Test...");
	Serial.print("SD:\t");
	Serial.println(BoolToString(TestSD()));
	Serial.print("I2C:\t");
	Serial.println(BoolToString(TestI2C()));
	Serial.print("Sense:\t");
	Serial.println(BoolToString(TestSensors()));
	Serial.print("RTC:\t");
	Serial.println(BoolToString(TestClock()));
	Serial.print("Current Time:\t");
	Serial.println(Clock.GetTime(MCP7940::Format::ISO_8601)); //FIX! //Grab time from Clock)
	Serial.println("...End Test");
	while(1);
}

bool TestSD() 
{
	pinMode(Pins::SD_EN, OUTPUT); //Ensure EN pin is setup as output
	digitalWrite(Pins::SD_EN, HIGH); //Set enable pin to turn on power

	boolean SDError = false;
	pinMode(Pins::SD_CS, OUTPUT);
	SPI.beginTransaction(SPISettings(4000000, MSBFIRST, SPI_MODE0));
	// SPI.setDataMode(SPI_MODE0);
	// SPI.setClockDivider(SPI_CLOCK_DIV2); //Sts SPI clock to 4 MHz for an 8 MHz system clock

	if(!SD_Init) {
		if (!SD.begin(Pins::SD_CS)) {
			if(Debug) Serial.println("Failed Init");
			SDError = true; 
			return SDError;
		}
		if(Debug) Serial.println("Initialized");
		SD_Init = true;
	}
	String FileName = "HWTest";

	(FileName + ".txt").toCharArray(FileNameC, 11);
	SD.remove(FileNameC); //Remove any previous files

	randomSeed(millis()); //Seed with a random number to try to endsure randomness
	int RandVal = random(30557); //Generate a random number between 0 and 30557 (the number of words in Hamlet)
	char RandDigits[5] = {0};
	sprintf(RandDigits, "%d", RandVal); //Convert RandVal into a series of digits
	int RandLength = (int)((ceil(log10(RandVal))+1)*sizeof(char)); //Find the length of the values in the array
//	Serial.print("Random Digits:"); //DEBUG!
//	for(int p = 0; p < 5; p++) { //DEBUG!
//	Serial.print(RandDigits[p]);
//	}
//	Serial.println(""); //DEBUG!

	File DataWrite = SD.open(FileNameC, FILE_WRITE);
	if(DataWrite) {
		DataWrite.println(RandVal);
		DataWrite.println("\nHe was a man. Take him for all in all.");
		DataWrite.println("I shall not look upon his like again.");
		DataWrite.println("-Hamlet, Act 1, Scene 2");
	}
	DataWrite.close();

	if(Debug){
		Serial.print("Random Value = "); Serial.println(RandVal);
	}

	char TestDigits[5] = {0};
	File DataRead = SD.open(FileNameC, FILE_READ);
	if(DataRead) {
		DataRead.read(TestDigits, RandLength);

		if(Debug){
		  Serial.print("Recieved Value = ");
		}
		for(int i = 0; i < RandLength - 1; i++){ //Test random value string
			if(Debug) Serial.print(TestDigits[i]);
			if(TestDigits[i] != RandDigits[i]) {
				SDError = true;
				Serial.print("x"); //DEBUG!
				Serial.print(RandDigits[i]);
			}
		}
		if(Debug) Serial.println("");

		if(Debug) {
		//      byte Data = DataRead.read();
			Serial.println("SD Test Data:");
			while(DataRead.available()) {
				Serial.write(DataRead.read());
			//        Data = DataRead.read();
			}
		}
	}
	DataRead.close();

	if(Debug) Serial.println("");

	SD.remove(FileNameC); //Remove dummy file created 

	return SDError;
}

bool TestI2C() //Test against fixed list 
{
	pinMode(Pins::SDA_CTRL, OUTPUT); //Setup SDA control as an output
	digitalWrite(Pins::SDA_CTRL, HIGH); //Set turn on on board SDA

	for(int i = 0; i < NumDevices; i++) {
		Wire.beginTransmission(ExpectedAddresses[i]);
		Wire.write(0x00);
		if(Wire.endTransmission() != 0) {
			Serial.println(ExpectedAddresses[i]);
			return 1; //Return failure if any device fails
		}
	}

	return 0; //If all devices return 0, then return passing state 
}

bool TestClock()
{
	bool Clock_Error = 1; //Default error
  pinMode(Pins::SDA_CTRL, OUTPUT); //Setup SDA control as an output
  digitalWrite(Pins::SDA_CTRL, HIGH); //Set turn on on board SDA
	pinMode(Pins::Clock_INT, INPUT); //Setup Clock pin as input
	// Serial.print("Start Time:\t");
	// Serial.println(Clock.GetTime(MCP7940::Format::ISO_8601)); //FIX! //Grab time from Clock)
  Clock.Begin();
  Clock.ClearAlarm(0);
  Clock.ClearAlarm(1);
  Clock.SetMode(MCP7940::Mode::Inverted); //Use dual alarm setup 
  Clock.SetTime(2021, 06, 10, 2, 12, 0, 0); //Set arbitrary time (incept date) //DEBUG!
	Clock.SetAlarm(5); //Set an alarm for 5 seconds from now

	unsigned long LocalTime = millis();
  // Serial.print("Alarm State = "); 
  // Serial.println(Clock.ReadAlarm());
	while(digitalRead(Pins::Clock_INT) != HIGH && (millis() - LocalTime < 7000)); //Wait for Clock to trigger, or 7 seconds to go by 
  // Serial.print("Alarm State = "); 
  // Serial.println(Clock.ReadAlarm());
	if(millis() - LocalTime < 7000 && (millis() - LocalTime > 3000)) { //Ensure time passed is greater than 3 seconds, less than 7 seconds 
		// Serial.print("End Time:\t");
		// Serial.println(return Clock.GetTime(MCP7940::Format::ISO_8601)); //FIX! //Grab time from Clock)
		if(Clock.ReadAlarm(0) == true) Clock_Error = 0; //Clear error
		else Clock_Error = 1; //Set error flag if interrupt bit not setg
	}
	else {
		// Serial.println("ERROR: No Alarm!");
		Clock_Error = 1; //Set alarm flag
	}

	return Clock_Error; //Return the resulting state
}

bool TestSensors()
{
	return 0; //FIX! 
}

String BoolToString(bool State)
{
	String Vals[] = {"Pass", "Fail"};
	return Vals[State]; //Return appropriate value based on State
}

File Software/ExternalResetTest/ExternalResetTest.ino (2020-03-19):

volatile bool Pulse = false; //Global flag to set on a pulse event 
const uint8_t PulsePin = 2; //Pin to measure pulse on

void setup() {
	Serial.begin(9600);
	Serial.println("Welcome to The Machine...");
	attachInterrupt(digitalPinToInterrupt(PulsePin), PulseEvent, FALLING); //Configure interrupt
}

void loop() {
	static unsigned long EventTime = millis(); //Used to keep track of time between events
	if(Pulse == true) {
		unsigned long EventDelta = millis() - EventTime; //Capture event time period immediately 
		EventTime = millis(); //Reset timing delta 
		Serial.print("Pulse Delta = ");
		Serial.print(EventDelta);
		Serial.println(" ms");
		Pulse = false; //Clear pulse flag
	}
}

void PulseEvent() 
{
	Pulse = true; //Set pulse flag
}

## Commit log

2020-02-13 Initial schematic capture for primary logger
    [PrimaryLogger.brd, PrimaryLogger.sch]
2020-02-14 Continued layout progress
    [PrimaryLogger.brd, PrimaryLogger.sch]
2020-02-15 Continued layout and preliminary board capture
    [PrimaryLogger.brd, PrimaryLogger.sch]
2020-02-17 BETA preliminary layout
    [PrimaryLogger.brd, PrimaryLogger.sch]
2020-02-18 Added gerbers and BoM for prelim quote
    [PrimaryLogger.brd, PrimaryLogger_BoM.csv]
2020-02-19 Updated BoM for advanced circuits quote
    [AdvancedCircuitsQuote_BoM_2020-02-18.xlsx, PrimaryLogger_BoM.csv]
2020-02-19 Minor updates to layout
    Added silk screen, added test points, other minor edits
    [PrimaryLogger.brd, PrimaryLogger.sch]
2020-02-21 Minor updates to make consistent with Soil Symbiont
    Changed 10uF to 0805 and mux to SC-70 package
    [PrimaryLogger.brd, PrimaryLogger.sch]
2020-02-22 Minor part value and silkscreen updates, gerbers generated
    [PrimaryLogger.brd, PrimaryLogger.sch]
2020-03-06 Minor silk screen update, post v0.0
    [PrimaryLogger.brd]
2020-03-13 Added I2C address info to schematic
    [PrimaryLogger.sch]
2020-03-13 Added pin definition documentation to README
2020-03-13 Added IO Expander pin info to readme
2020-04-20 Updated for v0.1, ready for fab
    [PrimaryLogger.brd, PrimaryLogger.sch]
2020-05-07 Updated part numbers
    [PrimaryLogger.brd, PrimaryLogger.sch]
2020-05-07 Fixed silk screen issue, updated version number and BoM
    Fixed minor silk screen issue in v0.1 (duplicate "PORT1" text on bottom), updated version number in schematic, generated new BoM with updated part numbers
    [PrimaryLogger.brd, PrimaryLogger.sch, PrimaryLogger_BoM.csv]
2020-07-15 Updated parts for BoM, moved designators, changed R41
    Updated part numbers to generate BoM, moved `R11` designator and changed `R41` to be `R12` to match ordering of rest of board (was carry over from Resnik I think)
    [PrimaryLogger.brd, PrimaryLogger.sch]
2020-12-14 Gerber and part updates
    Added Gerber files for Advanced Circuits order, minor changes to part numbers and BoMs
    [AdvancedCircuitsQuote_BoM_2020-09-17.xlsx, PrimaryLogger.brd, PrimaryLogger.sch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]
2020-12-14 Documentation and folder structure updates
    Moved around the folder structure, added board pictures, and added to README
    [AdvancedCircuitsQuote_BoM_2020-02-18.xlsx, PrimaryLogger.brd, PrimaryLogger.sch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]
2020-12-14 Further documentation updates
    Moved production files around, updated BoM in hardware and part libraries links to support that (DNP values issue)
    [AdvancedCircuitsQuote_BoM_2020-09-17.xlsx, PrimaryLogger.brd, PrimaryLogger.sch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]
2021-04-01 Added cropped board image
2021-04-01 Cleaned up schematic and made new PDF - final v0.2
    [PrimaryLogger.sch]
2021-04-01 Changed production folder structure, cleanup
    [AdvancedCircuitsQuote_BoM_2020-02-18.xlsx, AdvancedCircuitsQuote_BoM_2020-09-17.xlsx, PrimaryLogger_v2_BoM.csv]
2021-04-01 Added LED support for v0.3
    Schematic capture and preliminary layout of LED indicator
    [PrimaryLogger.brd, PrimaryLogger.sch]
2021-04-06 Updated IO expander to SSOP package
    [PrimaryLogger.brd, PrimaryLogger.sch]
2021-04-07 Added Niagara, jumpers, power connector
    [PrimaryLogger.brd, PrimaryLogger.sch]
2021-04-13 Cleanup and gerbers for v0.3A
    Cleanup of schematic and layout for v0.3A design
    [PrimaryLogger.brd, PrimaryLogger.sch]
2021-04-16 Updated part values for BoM generation
    [PrimaryLogger.brd, PrimaryLogger.sch]
2021-04-16 Generated BoM for v0.3
    [PrimaryLogger_BoM_0v3.csv]
2021-05-10 Minor updates v0.4A sent to fab
    Fixed layout issues and changed power topology for I2C buffer
    [PrimaryLogger.brd, PrimaryLogger.sch]
2021-05-18 v1.0 Updates
    Changed pinout and added connector to support preliminary talon development
    [PrimaryLogger.brd, PrimaryLogger.sch]
2021-06-02 Added build files for v0.4A board
    Added build files for v0.4A board for Caltronics quote, gerbers, pick and place, and zipped quote file
    [PrimaryLogger_0v4A_BoM.csv]
